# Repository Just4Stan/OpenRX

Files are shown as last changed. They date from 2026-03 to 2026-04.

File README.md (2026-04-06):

# OpenRX

Open-source ExpressLRS receiver family — four active boards:

- `OpenRX-Lite`: compact 2.4 GHz SX1281 receiver with ceramic antenna
- `OpenRX-Lite-UFL`: same as Lite with U.FL antenna connector
- `OpenRX-Mono`: single-LR1121 multi-band receiver with 1x U.FL
- `OpenRX-Gemini`: dual-LR1121 Gemini/Xrossband receiver with 2x U.FL

| Model | Band | RF | Front-End | Antenna | ELRS Target |
|---|---|-----|---|---|---|
| **Lite** | 2.4 GHz | SX1281 | 2450FM07D0034 BPF | Ceramic | `Unified_ESP32C3_2400_RX` |
| **Lite UFL** | 2.4 GHz | SX1281 | 2450FM07D0034 BPF | U.FL | `Unified_ESP32C3_2400_RX` |
| **Mono** | Multi-band | LR1121 | RFX2401C + SKY13414 + Johanson IPD | 1x U.FL | `Unified_ESP32C3_LR1121_RX` |
| **Gemini** | Xrossband | 2x LR1121 | 2x (RFX2401C + SKY13414 + Johanson IPD) | 2x U.FL | `Unified_ESP32C3_LR1121_RX` |

Mono and Gemini use the same firmware binary — `radio_nss_2` in hardware.json activates dual-radio mode.

## Active Schematics

- `OpenRX-Lite/esp32c3_sx1281_lite.kicad_sch`
- `OpenRX-Lite-UFL/esp32c3_sx1281_lite.kicad_sch`
- `OpenRX-Mono/esp32c3_lr1121_mono.kicad_sch`
- `OpenRX-Gemini/esp32c3_lr1121_gemini.kicad_sch`

## Documentation

- `OpenRX-Lite/DESIGN.md`
- `OpenRX-Lite-UFL/DESIGN.md`
- `OpenRX-Mono/DESIGN.md`
- `OpenRX-Gemini/DESIGN.md`

## Flashing

All boards expose `5V`, `GND`, `RX`, `TX` pads and a `BOOT` pad (GPIO9 to GND) for initial UART flashing. Mono and Gemini also have a tactile button on GPIO9. After first flash, use Wi-Fi OTA or Betaflight passthrough.

## ELRS Firmware Targets

Hardware JSON files are in `/shared/elrs-targets/`:

- `OpenRX Lite 2400.json`
- `OpenRX Mono LR1121.json`
- `OpenRX Gemini LR1121.json`
- `targets_entries.json`

## KiCad Libraries

All projects use KiCad 9 with project-local libraries only — no global library dependencies.

`shared/libs/` contains:

| Library | Contents |
|---|---|
| `OpenRX-Shared.kicad_sym` | Symbols: ESP32-C3, LR1121, SX1281, RFX2401C, SKY13414, TLV75533, Johanson IPD, 2450FM07D0034, antennas, LED, connectors |
| `OpenRX-Shared.pretty` | Footprints: QFN-14/16/24/32, X2SON, antenna, filter, LED, switch, solder pads |
| `OpenRX-Shared.3dshapes` | 3D models (.step + .wrl) |

All symbols include an `LCSC Part` property for JLCPCB BOM export.

## Datasheets

Shared local cache in `datasheets/common/`. All active IC/RF datasheets are present locally.

## Sourcing

Current low-stock / JLCPCB Global Sourcing candidates:

- `C255353` SKY13414-485LF
- `C19842466` 0900PC16J0042001E (consign from DigiKey)
- `C7498014` LR1121IMLTRT
- `C2151551` SX1281IMLTRT (for 1000 pcs Lite build)
- `C2651081` 2450FM07D0034

## License

**CERN Open Hardware Licence Version 2 - Strongly Reciprocal** ([CERN-OHL-S-2.0](https://ohwr.org/cern_ohl_s_v2.txt)). See [LICENSE](LICENSE).

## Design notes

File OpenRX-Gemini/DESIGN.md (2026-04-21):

# OpenRX-Gemini

Dual-LR1121 Gemini/Xrossband receiver. ESP32-C3 + 2x LR1121 + 2x RFX2401C + 2x SKY13414 + 2x Johanson IPD.

## Schematic

- Main sheet: `esp32c3_lr1121_gemini.kicad_sch`
- Radio A (U9 LR1121, U10 RFX2401C, U11 SKY13414): RF chain → `JP1` U.FL
- Radio B (U2 LR1121, U5 RFX2401C, U7 SKY13414): mirrors Radio A → `JP2` U.FL
- 2.4 GHz path per radio: `LR1121 RFIO_HF → 2450FM07D0034 (FL1/FL2) → RFX2401C → 0.3pF → SKY13414 RF4 → U.FL`
- Sub-GHz path per radio: `LR1121 → Johanson IPD (T1/T2) → SKY13414 RF1 (RX) / RF3 (TX HP) → U.FL`
- RF switch control (each radio controls its own switch): `DIO7 → V3, DIO8 → V2, V1 → GND`
- RFX2401C control (each radio controls its own FE): `DIO5 → RXEN, DIO6 → TXEN`
- ELRS sends `SetDioAsRfSwitch` to both radios simultaneously — wiring is symmetric so `radio_rfsw_ctrl` applies to both.

### SKY13414 Port Mapping (V1=GND, per switch)

| DIO7 (V3) | DIO8 (V2) | Port | Path |
|---|---|---|---|
| 0 | 0 | RF1 | Sub-GHz RX (IPD pin 6) |
| 1 | 0 | RF2 | NC |
| 0 | 1 | RF3 | Sub-GHz TX HP (IPD pin 9) |
| 1 | 1 | RF4 | 2.4GHz TX/RX (RFX2401C ANT) |

IPD TX_LP (pin 8) is disconnected — ELRS never uses LP PA on these boards.

### Status (2026-04-19, ELRS review)

All pre-fabrication schematic blockers resolved. Previously tracked bugs:

1. **DIO7-2 / DIO8-2 wiring:** FIXED — U7 (Radio B) V3/V2 tied to DIO7-2/DIO8-2, U11 (Radio A) V3/V2 tied to DIO7-1/DIO8-1. Each radio drives its own switch.
2. **Component swap:** DONE — filters migrated from `DEA102700LT-6307A2` to `2450FM07D0034T` (FL1 on Radio A, FL2 on Radio B), switches migrated from `SKY13588-460LF` to `SKY13414-485LF` (U7/U11).
3. **Ref designators:** filters renamed USB2→FL1 (Radio A) and USB1→FL2 (Radio B).

PCB routing, DRC, and on-hardware RF validation remain — see Release To-Do.

## Firmware

- ELRS target: `Unified_ESP32C3_LR1121_RX` (same binary as Mono)
- Hardware JSON: `/shared/elrs-targets/OpenRX Gemini LR1121.json`
- `radio_nss_2` enables dual-radio mode
- `radio_rfsw_ctrl: [15, 0, 0, 8, 8, 14, 0, 13]` — same as Mono, see Mono `DESIGN.md` for decode table (DIO5=RXEN, DIO6=TXEN, DIO7=V3, DIO8=V2)

## Flash Interface

- Pads: `5V`, `GND`, `RX`, `TX`
- `BOOT` pad + tactile button on GPIO9
- Hold BOOT/button during power-up for UART download mode
- Use Wi-Fi OTA after first flash

## Sourcing

- `C255353` SKY13414-485LF (x2)
- `C19842466` 0900PC16J0042001E (x2, consign from DigiKey)
- `C7498014` LR1121IMLTRT (x2)
- `C2651081` 2450FM07D0034T (x2)
- `C19213` RFX2401C (x2)

## Release To-Do

- Finish PCB routing / DRC
- Validate symmetric RF performance across both chains (NanoVNA)
- Run Gemini / Xrossband link validation on two LR1121-equipped TXs
- CE / RED pre-scan for dual-band operation

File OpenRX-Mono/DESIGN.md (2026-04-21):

# OpenRX-Mono

Single-LR1121 multi-band receiver. ESP32-C3 + LR1121 + RFX2401C + SKY13414 + Johanson IPD.

## Schematic

- Main sheet: `esp32c3_lr1121_mono.kicad_sch`
- Sub-GHz RX: `LR1121 pins 29-30 → IPD (T1) RX → SKY13414 RF1 → ANT → JP1 U.FL`
- Sub-GHz TX HP: `LR1121 pin 32 → IPD (T1) TX_HP → SKY13414 RF3 → ANT → JP1 U.FL`
- Sub-GHz TX LP: disconnected (IPD TX_LP pin 8 = NC, ELRS never uses LP PA)
- 2.4 GHz path: `LR1121 RFIO_HF → 2450FM07D0034 (USB2) → RFX2401C TXRX → PA/LNA → RFX2401C ANT → C16 0.3pF → SKY13414 RF4 → ANT → JP1 U.FL`
- RF switch control: `DIO7 → V3, DIO8 → V2, V1 → GND`
- RFX2401C control: `DIO5 → RXEN, DIO6 → TXEN`

### SKY13414 Port Mapping (V1=GND)

| DIO7 (V3) | DIO8 (V2) | Port | Path |
|---|---|---|---|
| 0 | 0 | RF1 | Sub-GHz RX (IPD pin 6) |
| 1 | 0 | RF2 | NC |
| 0 | 1 | RF3 | Sub-GHz TX HP (IPD pin 9) |
| 1 | 1 | RF4 | 2.4GHz TX/RX (RFX2401C ANT) |

IPD TX_LP (pin 8) is disconnected — ELRS never uses LP PA on these boards.

### 2450FM07D0034 Impedance Note

Filter pin 1 (chipset side) is 40 ohm, designed for SX1280/SX1281. LR1121 RFIO_HF is 50 ohm. Mismatch gives ~19 dB return loss (VSWR 1.25), only 0.05 dB mismatch loss — negligible. The filter's own internal return loss (14 dB typ) dominates. Keep as-is.

## Firmware

- ELRS target: `Unified_ESP32C3_LR1121_RX`
- Hardware JSON: `/shared/elrs-targets/OpenRX Mono LR1121.json`
- `radio_rfsw_ctrl: [15, 0, 0, 8, 8, 14, 0, 13]` — DIO5=RXEN, DIO6=TXEN, DIO7=V3, DIO8=V2

### rfsw_ctrl Decode

| Index | Mode | Value | Binary | DIO5 | DIO6 | DIO7 | DIO8 |
|---|---|---|---|---|---|---|---|
| 0 | Enable | 15 | 1111 | on | on | on | on |
| 1 | Standby | 0 | 0000 | 0 | 0 | 0 | 0 |
| 2 | SubGHz RX | 0 | 0000 | 0 | 0 | 0 | 0 |
| 3 | SubGHz TX LP | 8 | 1000 | 0 | 0 | 0 | 1 |
| 4 | SubGHz TX HP | 8 | 1000 | 0 | 0 | 0 | 1 |
| 5 | 2.4GHz TX | 14 | 1110 | 0 | 1 | 1 | 1 |
| 6 | unused | 0 | - | - | - | - | - |
| 7 | 2.4GHz RX | 13 | 1101 | 1 | 0 | 1 | 1 |

### GPIO Map

| GPIO | Function | LR1121 Pin |
|---|---|---|
| 1 | IRQ (DIO1) | 24 |
| 2 | RST | 6 |
| 3 | BUSY (DIO0) | 25 |
| 4 | MOSI | via SPI |
| 5 | MISO | via SPI |
| 6 | SCK | via SPI |
| 7 | NSS | via SPI |
| 8 | LED | - |
| 9 | Button | - |

## Flash Interface

- Pads: `5V`, `GND`, `RX`, `TX`
- `BOOT` pad + tactile button on GPIO9
- Hold BOOT/button during power-up for UART download mode
- Use Wi-Fi OTA after first flash

## Sourcing

- `C255353` SKY13414-485LF — 28K LCSC stock
- `C19842466` 0900PC16J0042001E — consign from DigiKey (~$0.49), 0 LCSC stock
- `C7498014` LR1121IMLTRT
- `C2651081` 2450FM07D0034
- `C19213` RFX2401C

## Release To-Do

- Finish PCB routing / DRC
- Validate RF path switching and rfsw_ctrl on hardware (NanoVNA)
- Run CE / RED pre-scan for 2.4 GHz and sub-GHz operation

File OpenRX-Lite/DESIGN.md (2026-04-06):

# OpenRX-Lite (Ceramic Antenna)

ESP32-C3 + SX1281, 2.4GHz only, ceramic antenna. Smallest and cheapest OpenRX receiver.

## Board Preview

| Front | Back |
|---|---|
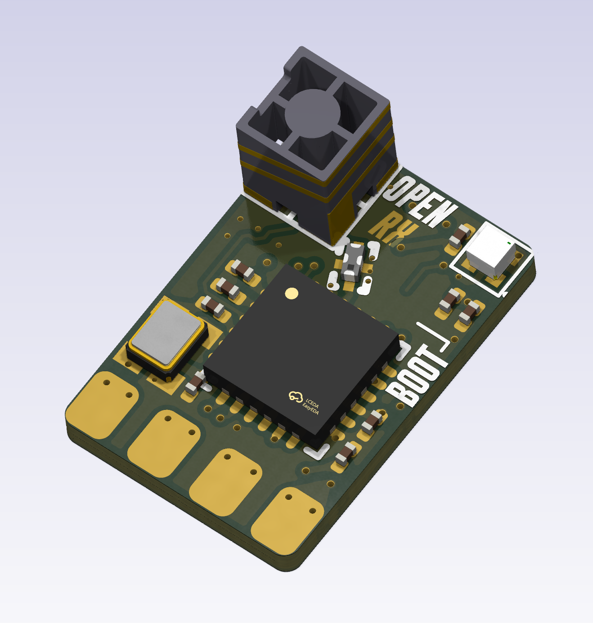
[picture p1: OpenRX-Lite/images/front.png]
Front
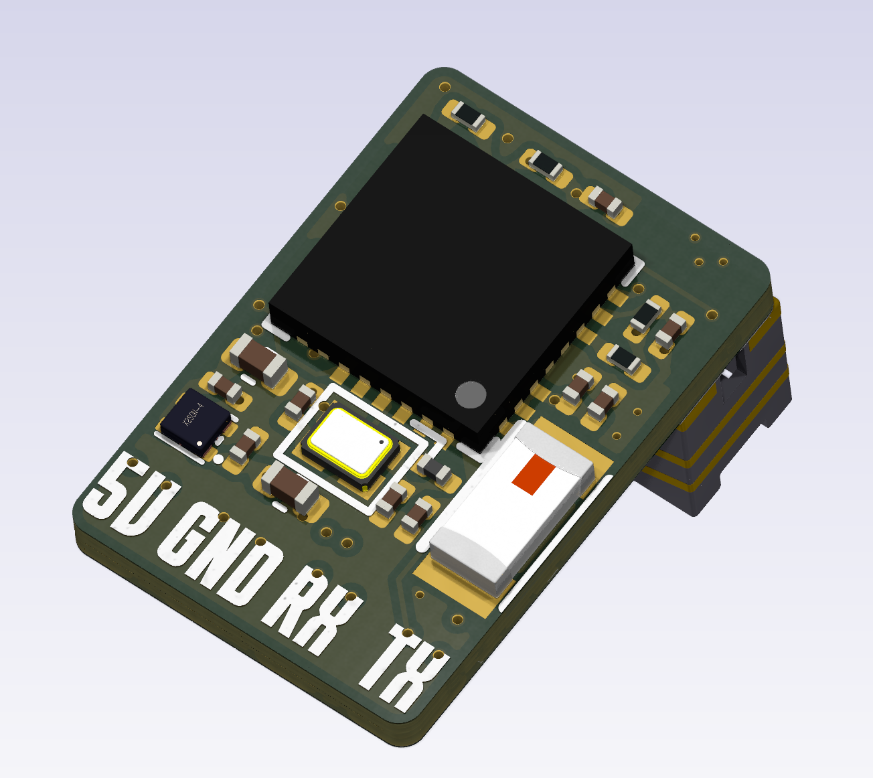
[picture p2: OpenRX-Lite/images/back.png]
Back
|  |  |

## Schematic

- Main sheet: `esp32c3_sx1281_lite.kicad_sch`
- RF chain: `SX1281 RFIO (pin 22) → 2450FM07D0034 (FL1) → 2450AT18A100E (AE1)`
- No RF front-end (PA/LNA), no RF switch, no sub-GHz
- 2450FM07D0034 pin 1 (40 ohm) matched to SX1281 RFIO — no mismatch
- TX power limited to SX1281 native +12.5 dBm (no PA)

### GPIO Map

| GPIO | Function |
|---|---|
| 2 | RST |
| 3 | BUSY |
| 4 | SCK |
| 5 | DIO1 |
| 6 | MISO |
| 7 | MOSI |
| 8 | NSS |
| 10 | LED |

Note: SPI pin mapping differs from Mono/Gemini. Lite uses GPIO4=SCK, GPIO6=MISO, GPIO7=MOSI, GPIO8=NSS. Mono uses GPIO6=SCK, GPIO5=MISO, GPIO4=MOSI, GPIO7=NSS. Different hardware.json required.

### No Boot Button

GPIO9 has a 10K pull-up but no physical switch. Enter UART download mode by shorting the BOOT pad to GND during power-up. WiFi mode cannot be entered at runtime without UART — firmware must be pre-configured or OTA-enabled on first flash.

## Firmware

- ELRS target: `Unified_ESP32C3_2400_RX`
- Hardware JSON: `/shared/elrs-targets/OpenRX Lite 2400.json`
- `power_values: [13]` — single power level, +12.5 dBm SX1281 native output

## Flash Interface

- Pads: `5V`, `GND`, `RX`, `TX`
- `BOOT` pad: short to GND during power-up to enter UART download mode
- Use Wi-Fi OTA after first flash

## Sourcing

- All parts LCSC basic/preferred where possible
- `C2651081` 2450FM07D0034 — 2.4GHz bandpass filter
- `C2151551` SX1281IMLTRT — watch stock for volume runs
- `C89334` 2450AT18A100E — ceramic chip antenna

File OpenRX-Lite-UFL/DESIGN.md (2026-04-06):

# OpenRX-Lite UFL

ESP32-C3 + SX1281, 2.4GHz only, UFL antenna connector. Same circuit as Lite ceramic, different antenna interface.

## Board Preview

| Front | Back |
|---|---|
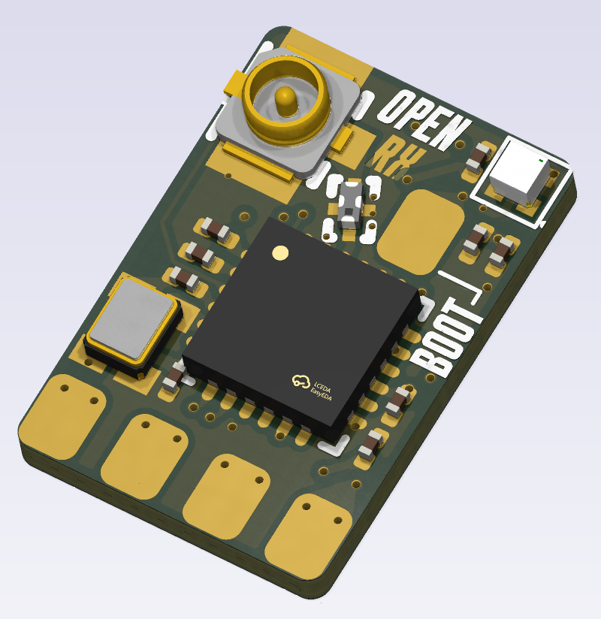
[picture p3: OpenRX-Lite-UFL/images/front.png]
Front
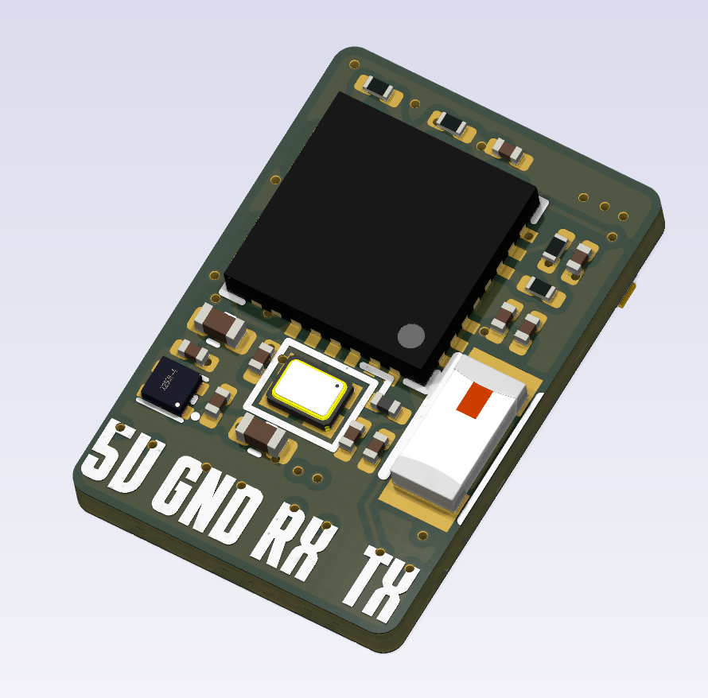
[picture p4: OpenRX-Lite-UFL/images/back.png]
Back
|  |  |

## Schematic

- Main sheet: `esp32c3_sx1281_lite.kicad_sch`
- RF chain: `SX1281 RFIO (pin 22) → 2450FM07D0034 (FL1) → U.FL-R-SMT-1(80) (JP1)`
- AE1 (2450AT18A100E) still in BOM — DNP or WiFi antenna for ESP32-C3
- No RF front-end (PA/LNA), no RF switch, no sub-GHz
- 2450FM07D0034 output is 50 ohm → U.FL is 50 ohm. Clean match.

### GPIO Map

Same as Lite ceramic — see `OpenRX-Lite/DESIGN.md`.

### No Boot Button

Same as Lite ceramic — GPIO9 pull-up only, no physical switch.

## Firmware

- ELRS target: `Unified_ESP32C3_2400_RX` (same as ceramic Lite)
- Hardware JSON: `/shared/elrs-targets/OpenRX Lite 2400.json`

## Flash Interface

- Pads: `5V`, `GND`, `RX`, `TX`
- `BOOT` pad: short to GND during power-up to enter UART download mode
- Use Wi-Fi OTA after first flash

## Sourcing

- All parts LCSC basic/preferred where possible
- `C2651081` 2450FM07D0034 — 2.4GHz bandpass filter
- `C2151551` SX1281IMLTRT — watch stock for volume runs
- `C88374` U.FL-R-SMT-1(80) — antenna connector

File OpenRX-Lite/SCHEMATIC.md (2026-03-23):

# OpenRX-Lite Schematic Documentation

Budget 2.4GHz ExpressLRS receiver. No PA/LNA, no UFL -- direct SX1281 to ceramic chip antenna.

- PCB: 16x12mm, 2-layer, 1.0mm thickness
- Target BOM: EUR 3-4
- Input: 3.3-5V from flight controller

## Block Diagram

```
                                    +3.3V
                                      |
  +-----+    +--------+    +---------+----------+
  | FC   |    |ME6211  |    |                    |
  | 5V---|----| LDO    |----|  ESP32-C3FH4       |
  | GND--|--+-| 3.3V   |    |  (QFN-32, 5x5mm)  |
  | TX---|--|-|--------|----| GPIO1/RX           |
  | RX---|--|-|--------|----| GPIO0/TX           |
  +-----+  | |        |    |                    |    SPI Bus
            | +--------+    |  GPIO4/SCK  -------+--------+
            |               |  GPIO7/MOSI -------+-----+  |
            |               |  GPIO6/MISO -------+--+  |  |
            |               |  GPIO8/NSS  -------+-+|  |  |
            |               |  GPIO5/DIO1 ------+| ||  |  |
            |               |  GPIO3/BUSY -----+|| ||  |  |
            |               |  GPIO2/NRST ----+||| ||  |  |
            |               |                 |||| ||  |  |
            |     40MHz     |  XTAL_P/N       |||| ||  |  |
            |    +-----+    |    |  |          |||| ||  |  |
            |    | XTAL|----+----+--+          |||| ||  |  |
            |    +-----+    |                  |||| ||  |  |
            |               | GPIO10 ---> WS2812B (opt)    |
            |               | GPIO9  ---> BOOT btn         |
            |               | GPIO18 ---> USB D- (TP)      |
            |               | GPIO19 ---> USB D+ (TP)      |
            |               +----------+   |||| ||  |  |
            |                              |||| ||  |  |
            |               +----------+   |||| ||  |  |
            |    52MHz      |SX1281    |   |||| ||  |  |
            |   +------+    |IMLTRT   |   |||| ||  |  |
            |   | TCXO |----|XTA      |   |||| ||  |  |
            |   +------+    |         |   |||| ||  |  |
            |               |NRESET---+---+||| ||  |  |
            |               |BUSY  --------+|| ||  |  |
            |               |DIO1  ---------+| ||  |  |
            |               |NSS   ----------+ ||  |  |
            |               |MISO  -------------+  |  |
            |               |MOSI  ----------------+  |
            |               |SCK   -------------------+
            |               |         |
            |               |  RFIO   |
            |               +----+----+
            |                    |
            |               L-match network
            |               2.2nH + 1.0pF
            |                    |
            |               +----------+
            |               | Ceramic  |
            |               | Antenna  |
            |               | 2450AT   |
            |               +----------+
            |
            +--- GND plane
```

## Power Supply (U3: ME6211C33M5G-N)

SOT-23-5, 500mA, LDO 3.3V regulator. LCSC C82942.

```
         5V IN
          |
          +--+--[C1 10uF]--+--GND
          |  |              |
          |  +--[C2 100nF]--+
          |
     +----+----+
     |1  VIN   |
     |         |
     |2  VOUT--+--+--[C3 22uF]--+--GND
     |         |  |              |
     |3  CE    |  +--[C4 100nF]--+
     |   (=VIN)|  |
     |4  GND   |  +--- 3.3V RAIL
     |5  NC    |
     +---------+
```

### Pin-by-pin: ME6211C33M5G-N (SOT-23-5)

| Pin | Name | Connection |
|-----|---|---|
| 1 | VIN | 5V input rail. C1 (10uF 0603 X5R) + C2 (100nF 0402 X7R) to GND |
| 2 | VOUT | 3.3V output rail. C3 (22uF 0603 X5R) + C4 (100nF 0402 X7R) to GND |
| 3 | CE (chip enable) | Tied to VIN (always on) |
| 4 | GND | Ground |
| 5 | NC | No connect |

## ESP32-C3FH4 (U1, QFN-32, 5x5mm)

LCSC C2858491. RISC-V single core, 160MHz, 4MB internal flash, WiFi+BLE.

### Pin-by-pin: ESP32-C3FH4 (QFN-32)

| Pin | Name | Connection | Notes |
|-----|---|---|---|
| 1 | GND | GND | |
| 2 | GND | GND | |
| 3 | 3V3 | 3.3V rail, 100nF (C5) to GND | Main power |
| 4 | EN (CHIP_EN) | 10k (R1) pull-up to 3.3V + 1uF (C6) to GND | RC delay per Espressif spec. Provides stable power-on reset. |
| 5 | GPIO4 | SX1281 SCK (pin 18) | SPI clock |
| 6 | GPIO5 | SX1281 DIO1 (pin 5) | Radio interrupt (active high) |
| 7 | GPIO6 | SX1281 MISO (pin 16) | SPI data from radio |
| 8 | GPIO7 | SX1281 MOSI (pin 17) | SPI data to radio |
| 9 | GPIO8 | SX1281 NSS (pin 19) + 10k (R2) pull-up to 3.3V | SPI chip select (active low). Pull-up keeps radio deselected during ESP boot. |
| 10 | GPIO9 | BOOT button (SW1) to GND + 10k (R3) pull-up to 3.3V | Hold low during reset to enter USB/UART bootloader. Internal pull-up exists but external recommended. |
| 11 | GPIO10 | WS2812B LED data (D1) | Optional status LED. Series 100R (R4) recommended. |
| 12 | GND | GND | |
| 13 | GPIO18 (USB_D-) | Test pad TP1 | Native USB for flashing. Optional -- can use UART instead. |
| 14 | GPIO19 (USB_D+) | Test pad TP2 | Native USB for flashing. Optional. |
| 15 | GPIO3 | SX1281 BUSY (pin 4) | Radio busy status (active high). Poll before SPI commands. |
| 16 | GPIO2 | SX1281 NRESETn (pin 3) | Radio hardware reset (active low). ESP drives low to reset SX1281. |
| 17 | GPIO1 (RX) | FC connector pad TX (CRSF from FC) | UART RX. FC TX connects to ESP RX. 3.3V logic. |
| 18 | GPIO0 (TX) | FC connector pad RX (CRSF to FC) | UART TX. ESP TX connects to FC RX. |
| 19 | GND | GND | |
| 20 | XTAL_P | 40MHz crystal (Y1) pin 1 + 10pF (C7) to GND | Crystal load cap. Place crystal close to pins 20/21. |
| 21 | XTAL_N | 40MHz crystal (Y1) pin 3 + 10pF (C8) to GND | Crystal load cap. |
| 22-30 | GND/NC | GND or NC per datasheet | Unused GPIO and supply pins tied to GND |
| 31 | GND | GND | |
| 32 | GND | GND | |
| EP | Exposed pad | GND | Thermal pad, multiple vias to ground plane |

**Critical notes for ESP32-C3FH4:**
- Pin 4 (EN) RC time constant: 10k * 1uF = 10ms. This ensures clean power-on reset.
- GPIO9 is the boot mode strapping pin. HIGH = normal boot from flash. LOW during reset = download mode.
- GPIO8 is also a strapping pin. Must be HIGH during boot (pull-up on NSS line handles this).
- GPIO2 is a strapping pin. Defaults to HIGH (floating). OK since SX1281 NRESET is active low.
- The ESP32-C3FH4 has 4MB flash internal -- no external flash needed.
- 40MHz crystal is mandatory. Cannot use internal RC oscillator for WiFi/BLE.
- Thermal pad MUST be soldered to GND with thermal vias.

## SX1281IMLTRT (U2, QFN-24, 4x4mm)

LCSC C2151551. 2.4GHz LoRa/FLRC/FSK transceiver. Used in LDO mode (no external inductor).

### Pin-by-pin: SX1281IMLTRT (QFN-24)

| Pin | Name | Connection | Notes |
|-----|---|---|---|
| 1 | VDD | 3.3V through 100nF (C9) to GND | Digital supply |
| 2 | VDD_IN | 3.3V through 100nF (C10) to GND | CRITICAL: Must be connected. Main power input for internal LDO/DC-DC. |
| 3 | NRESETn | ESP32-C3 GPIO2 (pin 16) + 10k (R5) pull-up to 3.3V + 100nF (C11) to GND | Active low reset. RC provides power-on reset. ESP can drive low for hard reset. |
| 4 | BUSY | ESP32-C3 GPIO3 (pin 15) | Active high when radio is processing a command. Poll before SPI transactions. |
| 5 | DIO1 | ESP32-C3 GPIO5 (pin 6) | Main interrupt output. Directly connected. |
| 6 | DIO2 | NC | Not used in this design. Can be used for RF switch control in designs with PA/LNA. |
| 7 | DIO3 | NC | Not used. Can output 32MHz clock for TCXO enable but we use always-on TCXO. |
| 8 | GND | GND | |
| 9 | GND | GND | |
| 10 | VR_PA | 470nF (C12) to GND | LDO mode: This is the PA regulator output. 470nF decoupling required. NO inductor (inductor only needed in DC-DC mode). |
| 11 | VDD | 3.3V through 100nF (C13) to GND | RF/analog supply |
| 12 | XTA | 52MHz TCXO output (Y2 pin 3) | TCXO clock input. AC coupling cap may be needed (10pF, C14) depending on TCXO output type. If TCXO is clipped sine output, direct connection OK. |
| 13 | XTB | NC (floating) | Only used in crystal mode. Leave floating for TCXO mode. |
| 14 | GND | GND | |
| 15 | RFIO | L-match network to antenna | See RF Path section below |
| 16 | MISO | ESP32-C3 GPIO6 (pin 7) | SPI data output |
| 17 | MOSI | ESP32-C3 GPIO7 (pin 8) | SPI data input |
| 18 | SCK | ESP32-C3 GPIO4 (pin 5) | SPI clock input |
| 19 | NSS | ESP32-C3 GPIO8 (pin 9) + 10k (R2) pull-up to 3.3V | SPI chip select, active low. Shared pull-up with ESP side. |
| 20 | GND | GND | |
| 21 | GND | GND | |
| 22 | GND | GND | |
| 23 | GND | GND | |
| 24 | GND | GND | |
| EP | Exposed pad | GND | Thermal pad. Multiple vias to GND plane. |

**Critical notes for SX1281:**
- LDO mode selected: VR_PA (pin 10) gets 470nF cap only. No inductor.
- DC-DC mode would require 15nH inductor on VR_PA but adds layout complexity on 2-layer board. Not worth it for a receiver.
- VDD_IN (pin 2) MUST be connected to 3.3V. Common mistake to leave it floating.
- TCXO mode: Set register UseRegulatorMode and configure TCXO in firmware. DIO3 can control TCXO power but we run TCXO always-on from 3.3V for simplicity.
- Max SPI clock: 16MHz. ESP32-C3 SPI peripheral should be configured accordingly.
- BUSY must be polled before every SPI transaction. Do not rely on timing.

## 52MHz TCXO (Y2: OW7EL89CENUNFAYLC-52M)

LCSC C22434896. SMD 2016-4P (2.0x1.6mm). YXC, 3.3V, +/-0.5ppm.

### Pin-by-pin: TCXO (SMD2016-4P)

| Pin | Name | Connection |
|-----|---|---|
| 1 | VDD | 3.3V through 100nF (C15) to GND |
| 2 | GND | GND |
| 3 | OUTPUT | SX1281 XTA (pin 12). Direct connection if clipped sine output. Add 10pF AC coupling cap (C14) if DC blocking needed. |
| 4 | GND | GND |

**Notes:**
- TCXO provides temperature-stable 52MHz reference. Prevents frequency drift disconnections that plague crystal-based ELRS receivers.
- +/-0.5ppm stability is excellent. SX1281 datasheet requires better than +/-5ppm for reliable FLRC mode.
- Always-on (powered from 3.3V rail directly). No DIO3 control needed.
- Place close to SX1281 XTA pin. Keep trace short and away from digital signals.

## 40MHz Crystal (Y1: CJ17-400001010B20)

LCSC C2875272. SMD 1612-4P (1.6x1.2mm). Changjing, 10pF load, +/-10ppm.

### Pin-by-pin: Crystal (SMD1612-4P)

| Pin | Name | Connection |
|-----|---|---|
| 1 | XIN | ESP32-C3 XTAL_P (pin 20) + 10pF (C7) to GND |
| 2 | GND | GND |
| 3 | XOUT | ESP32-C3 XTAL_N (pin 21) + 10pF (C8) to GND |
| 4 | GND | GND |

**Notes:**
- 10pF load caps match crystal specification. Actual capacitance seen by crystal = (C_load1 * C_load2) / (C_load1 + C_load2) + C_stray. With 10pF caps and ~2-3pF stray, effective load is ~7-8pF. May need to adjust to 12pF caps if frequency is off.
- Place as close to ESP32-C3 XTAL pins as possible. Route traces as short differential pair.
- Guard ring on GND plane around crystal traces recommended.
- Keep copper pour away from crystal on the other layer.

## RF Path (Antenna Matching)

No PA/LNA. Direct connection from SX1281 RFIO to ceramic antenna through L-match network.

```
SX1281          L-match              Ceramic Antenna
RFIO  ---[L1 2.2nH]---+---[feed]--- 2450AT18A100E
(pin 15)               |             (Johanson)
                   [C16 1.0pF]
                       |
                      GND
```

### Components:
- L1: 2.2nH inductor, 0402, high-Q (>30 at 2.4GHz). LCSC basic part preferred.
- C16: 1.0pF capacitor, 0402, C0G/NP0. Tight tolerance (+/-0.1pF if possible).

### Ceramic Antenna: 2450AT18A100E (ANT1)

LCSC C89334. Johanson, 3.2x1.6mm chip antenna.

**Notes:**
- Antenna MUST be placed at PCB edge with ground plane keepout per Johanson application note.
- Minimum 1mm clearance from antenna feed to GND pour on top layer.
- Ground plane on bottom layer should extend under antenna for return path.
- Antenna impedance is nominally 50 ohm but varies with ground plane geometry. L-match values (2.2nH/1.0pF) are starting points -- tune with VNA on actual PCB.
- No copper (signal or ground) on the same layer as antenna within keepout zone.
- Performance will be significantly worse than external antenna. Expected range: 200-500m line of sight with ELRS 500Hz mode. Adequate for typical FPV use (proximity/indoor/whoops).

## WS2812B LED (D1, Optional)

Standard addressable RGB LED for status indication.

| Connection | Detail |
|---|---|
| VDD | 3.3V (WS2812B works at 3.3V, some variants need 5V -- check datasheet) |
| DIN | ESP32-C3 GPIO10 (pin 11) through 100R series resistor (R4) |
| DOUT | NC |
| GND | GND |
| Decoupling | 100nF (C17) close to VDD pin |

Note: WS2812B is optional. Omit to save BOM cost and board space. ELRS firmware can function without LED.

## Boot Button (SW1)

Tactile switch, normally open.

| Connection | Detail |
|---|---|
| One side | ESP32-C3 GPIO9 (pin 10) |
| Other side | GND |
| Pull-up | 10k (R3) from GPIO9 to 3.3V |

Hold button during power-on or reset to enter bootloader (USB or UART download mode).

Note: For production, this can be replaced with solder pads or omitted entirely if UART flashing via FC connection is sufficient. ELRS uses its own bootloader passthrough via UART.

## Connector Pads (J1)

4 castellated or solder pads, 1.27mm pitch, at PCB edge.

| Pad | Signal | Notes |
|-----|---|---|
| 1 | 5V | Power input from FC. 3.3-5V range (LDO input). |
| 2 | GND | Ground |
| 3 | TX | ESP32-C3 GPIO0/TX. CRSF data TO flight controller. Connect to FC RX pad. |
| 4 | RX | ESP32-C3 GPIO1/RX. CRSF data FROM flight controller. Connect to FC TX pad. |

## Test Pads

| Pad | Signal | Notes |
|-----|---|---|
| TP1 | USB D- | ESP32-C3 GPIO18. For USB flashing during development. |
| TP2 | USB D+ | ESP32-C3 GPIO19. For USB flashing during development. |

## Complete Decoupling Capacitor Summary

| Designator | Value | Package | Location | IC/Pin |
|---|---|---|---|---|
| C1 | 10uF | 0603 X5R 10V | LDO input | U3 VIN |
| C2 | 100nF | 0402 X7R 16V | LDO input | U3 VIN |
| C3 | 22uF | 0603 X5R 10V | LDO output | U3 VOUT |
| C4 | 100nF | 0402 X7R 16V | LDO output | U3 VOUT |
| C5 | 100nF | 0402 X7R 16V | ESP32 3V3 | U1 pin 3 |
| C6 | 1uF | 0402 X5R 10V | ESP32 EN | U1 pin 4 (with R1) |
| C7 | 10pF | 0402 C0G 50V | Crystal load | U1 XTAL_P (pin 20) |
| C8 | 10pF | 0402 C0G 50V | Crystal load | U1 XTAL_N (pin 21) |
| C9 | 100nF | 0402 X7R 16V | SX1281 VDD | U2 pin 1 |
| C10 | 100nF | 0402 X7R 16V | SX1281 VDD_IN | U2 pin 2 |
| C11 | 100nF | 0402 X7R 16V | SX1281 NRESET | U2 pin 3 (with R5) |
| C12 | 470nF | 0402 X5R 10V | SX1281 VR_PA | U2 pin 10 (LDO mode) |
| C13 | 100nF | 0402 X7R 16V | SX1281 VDD | U2 pin 11 |
| C14 | 10pF | 0402 C0G 50V | TCXO AC coupling | Y2 out to U2 XTA (optional) |
| C15 | 100nF | 0402 X7R 16V | TCXO VDD | Y2 pin 1 |
| C16 | 1.0pF | 0402 C0G 50V | Antenna match | Shunt to GND in L-match |
| C17 | 100nF | 0402 X7R 16V | WS2812B VDD | D1 (optional) |

## Complete Resistor Summary

| Designator | Value | Package | Location |
|---|---|---|---|
| R1 | 10k | 0402 | ESP32 EN pull-up |
| R2 | 10k | 0402 | SPI NSS pull-up (shared ESP/SX1281) |
| R3 | 10k | 0402 | BOOT button pull-up |
| R4 | 100R | 0402 | WS2812B data series resistor (optional) |
| R5 | 10k | 0402 | SX1281 NRESET pull-up |

## Complete Inductor Summary

| Designator | Value | Package | Location |
|---|---|---|---|
| L1 | 2.2nH | 0402 | Antenna L-match series inductor |

## Design Notes and Considerations

### Power Budget
- ESP32-C3 active (WiFi off, CPU running): ~30mA
- SX1281 RX mode: ~7mA
- SX1281 TX mode (no PA): ~25mA at +12.5dBm
- TCXO: ~1.5mA
- WS2812B: ~1mA idle, ~20mA full white
- Total typical (RX mode): ~40mA
- ME6211 500mA capacity provides ample margin

### Layout Priorities (2-layer board)
1. SX1281 ground pad: Maximize thermal vias to bottom GND plane
2. ESP32-C3 ground pad: Same treatment
3. Crystal placement: As close to ESP XTAL pins as physically possible
4. TCXO placement: As close to SX1281 XTA as possible
5. Antenna: At PCB edge, ground plane keepout per Johanson app note
6. Decoupling caps: Each cap within 1mm of its associated IC pin
7. SPI traces: Keep short, matched length not critical at 16MHz max
8. RF trace (RFIO to antenna): 50 ohm controlled impedance if possible. On 2-layer 1.0mm FR4, approximately 1.8mm trace width for 50 ohm microstrip. Short trace length minimizes mismatch impact.

### 2-Layer Stackup (JLCPCB 1.0mm)
- Top: Components, signal routing, RF trace
- Bottom: Continuous GND plane (maximise pour). Route signals on top only where possible.

### Firmware Considerations
- ExpressLRS firmware must be configured for:
  - SX1281 (not SX1280 -- SX1281 has LNA built in)
  - TCXO mode (not crystal)
  - LDO mode (not DC-DC)
  - No PA/LNA control pins
  - GPIO mappings matching this schematic
- CRSF protocol on UART at 420000 baud (ELRS default)
- Binding phrase set in firmware build

### Known Limitations
- No diversity (single antenna, single radio)
- No PA: TX power limited to SX1281 native +12.5dBm max
- No LNA: RX sensitivity limited to SX1281 native (~-105dBm for LoRa, ~-98dBm for FLRC)
- Range estimate: 200-500m LOS at 500Hz, 1-2km at 50Hz. Adequate for proximity/indoor/whoop flying.
- 2-layer RF: Impedance control less precise than 4-layer. Antenna match will need bench tuning.
- Ceramic antenna: ~2-3dB gain penalty vs external dipole/T-antenna

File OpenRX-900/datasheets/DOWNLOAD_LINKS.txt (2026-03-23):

# OpenRX-900 Datasheets - Download Manually

## LR1121 (already downloaded as LR1121_datasheet_v1.1.pdf)
https://cdn.hackaday.io/files/1901428135035328/LR1121_data_sheet_V1_1.pdf

## ESP32-C3 Datasheet
https://www.espressif.com/sites/default/files/documentation/esp32-c3_datasheet_en.pdf

## ESP32-C3 Hardware Design Guidelines
https://www.espressif.com/sites/default/files/documentation/esp32-c3_hardware_design_guidelines_en.pdf

## ME6211C LDO Datasheet
https://datasheet.lcsc.com/lcsc/1811131510_MICRONE-Nanjing-Micro-One-Elec-ME6211C33M5G-N_C82942.pdf

## LR1121 User Manual
https://www.mouser.com/pdfDocs/UserManual_LR1121_v1_1.pdf

## LR1121 PCB Design Guidelines (AN1200.66)
https://www.semtech.com (search for AN1200.66)

## LR1121 IPD Reference Design (AN1200.76)
https://www.semtech.com (search for AN1200.76)

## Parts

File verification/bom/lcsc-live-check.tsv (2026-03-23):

LCSC | MPN | PriceUSD | Availability | Inventory | Description
C106225 | RC0201FR-0710KL | 0.0006 | InStock | 1342400 | 50mW 10kΩ 25V Thick Film Resistor ±1% ±200ppm/℃ 0201 Chip Resistor - Surface Mount RoHS
C152351 | 479480001 | 0.7028 | InStock | 18195 | RF ANTENNA 2.4G Surface Mount,3.2x4mm
C15525 | CL05A106MQ5NUNC | 0.0037 | InStock | 2592700 | 10uF ±20% 6.3V Ceramic Capacitor X5R 0402
C19213 | RFX2401C | 0.5059 | InStock | 59827 | 2V~3.6V ZigBee 2.4GHz~2.5GHz QFN-16-EP(3x3) RF Front End (LNA + PA) RoHS
C19842466 | 0900PC16J0042001E | 0.5236 | OutOfStock | 0 | 10dB 868MHz~928MHz 1dB 50Ω:50Ω Balun RoHS
C20069240 | CGA0201C0G100J500ET | 0.0003 | InStock | 69600 | 10pF ±5% 50V Ceramic Capacitor C0G 0201
C206441 | LQP03TN24NH02D | 0.0050 | InStock | 8600 | 140mA 24nH 2.3Ω Thick Film Inductor ±3% 0201 Fixed Inductors RoHS
C2151551 | SX1281IMLTRT | 2.2643 | InStock | 1168 | 2Mbps -132dBm 2.4GHz~2.5GHz 2.4GHz 1.8V~3.7V QFN-24-EP(4x4) RF Transceiver ICs RoHS
C22434888 | OW2EL89CENUXFMYLC-32M | 0.4605 | InStock | 2782 | 32MHz SMD3225-4P Oscillators RoHS
C22434896 | OW7EL89CENUNFAYLC-52M | 0.4208 | InStock | 12605 | 52MHz SMD2016-4P Oscillators RoHS
C23733 | CL05A475MP5NRNC | 0.0028 | InStock | 2177450 | 4.7uF ±20% 10V Ceramic Capacitor X5R 0402
C270364 | 0201WMF1003TEE | 0.0005 | InStock | 2096600 | 100kΩ ±1% 50mW 0201 Thick Film Resistor
C274342 | RC0201FR-07220RL | 0.0005 | InStock | 22100 | 50mW 220Ω 25V Thick Film Resistor ±1% ±200ppm/℃ 0201 Chip Resistor - Surface Mount RoHS
C2858491 | ESP32-C3FH4 | 1.5592 | InStock | 1783 | QFN-32-EP(5x5) RF Transceiver Modules and Modems RoHS
C2861882 | TLV75533PDQNR | 0.0915 | InStock | 2610 | Linear Voltage Regulator IC Positive Fixed 1 Output 500mA X2-SON-4-EP(1x1)
C2875272 | CJ17-400001010B20 | 0.1484 | InStock | 15 | Crystal 40MHz ±10ppm 10pF SMD1612-4P
C5349953 | XL-1010RGBC-2812B | 0.0395 | InStock | 1045460 | SMD,1x1mm LED Addressable, Specialty RoHS
C574024 | DEA102700LT-6307A2 | 0.0544 | InStock | 5385 | 50Ω 0.45dB SMD-4P,1x0.5mm RF Filters RoHS
C62164 | 0201CG180J500NT | 0.0004 | InStock | 280900 | 18pF ±5% 50V Ceramic Capacitor C0G 0201
C62548 | 0201B221K500NT | 0.0004 | InStock | 209600 | 220pF ±10% 50V Ceramic Capacitor X7R 0201
C66942 | 0201B102K500NT | 0.0004 | InStock | 537800 | 1nF ±10% 50V Ceramic Capacitor X7R 0201
C6808014 | AHW1608FE100KTF | 0.0174 | InStock | 39500 | 280mA 10uH 2.4Ω Wire-wound chip inductor ±10% 0603 Fixed Inductors RoHS
C7498014 | LR1121IMLTRT | 3.0399 | InStock | 1439 | 101.5Kbps -108dBm 1.8V~3.7V QFN-32-EP(5x5) RF Transceiver ICs RoHS
C76935 | GRM033R61A105ME44D | 0.0016 | InStock | 676000 | 1uF ±20% 10V Ceramic Capacitor X5R 0201
C76939 | GRM033R61E104KE14D | 0.0018 | InStock | 1336800 | 100nF ±10% 25V Ceramic Capacitor X5R 0201
C85926 | GRM033R60J474KE90D | 0.0014 | InStock | 508900 | 470nF ±10% 6.3V Ceramic Capacitor X5R 0201
C88374 | U.FL-R-SMT-1(80) | 0.0769 | InStock | 243610 | Connector Receptacle IPEX Male Pin 50Ω Surface Mount
C89334 | 2450AT18A100E | 0.3117 | InStock | 3385 | RF ANTENNA 2.4G Surface Mount 1206

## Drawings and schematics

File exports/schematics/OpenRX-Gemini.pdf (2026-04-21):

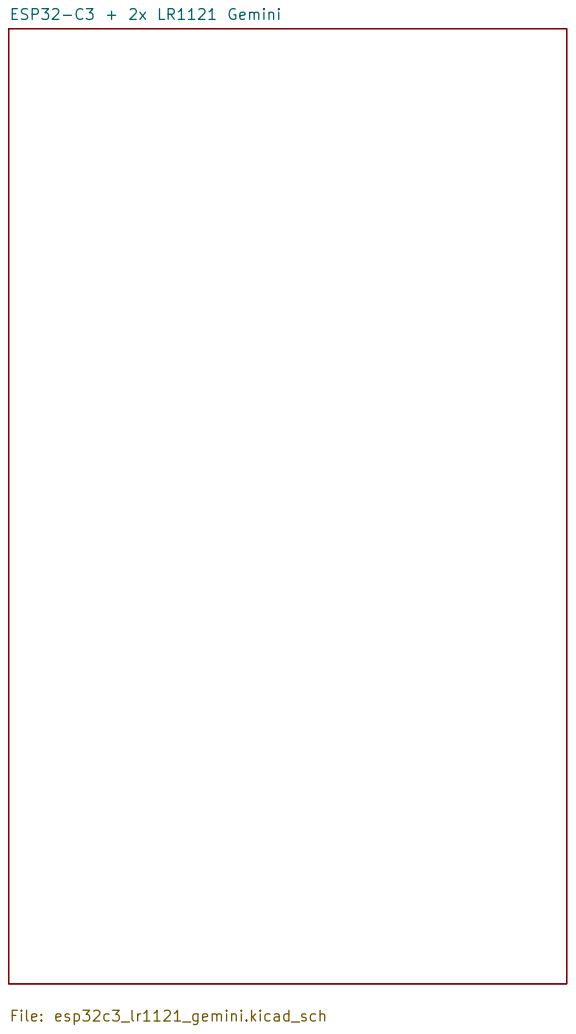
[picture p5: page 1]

Size: A3 | Rev: | F Date:
KiCad E.D.A. 10.0.0 | Id: 1/2

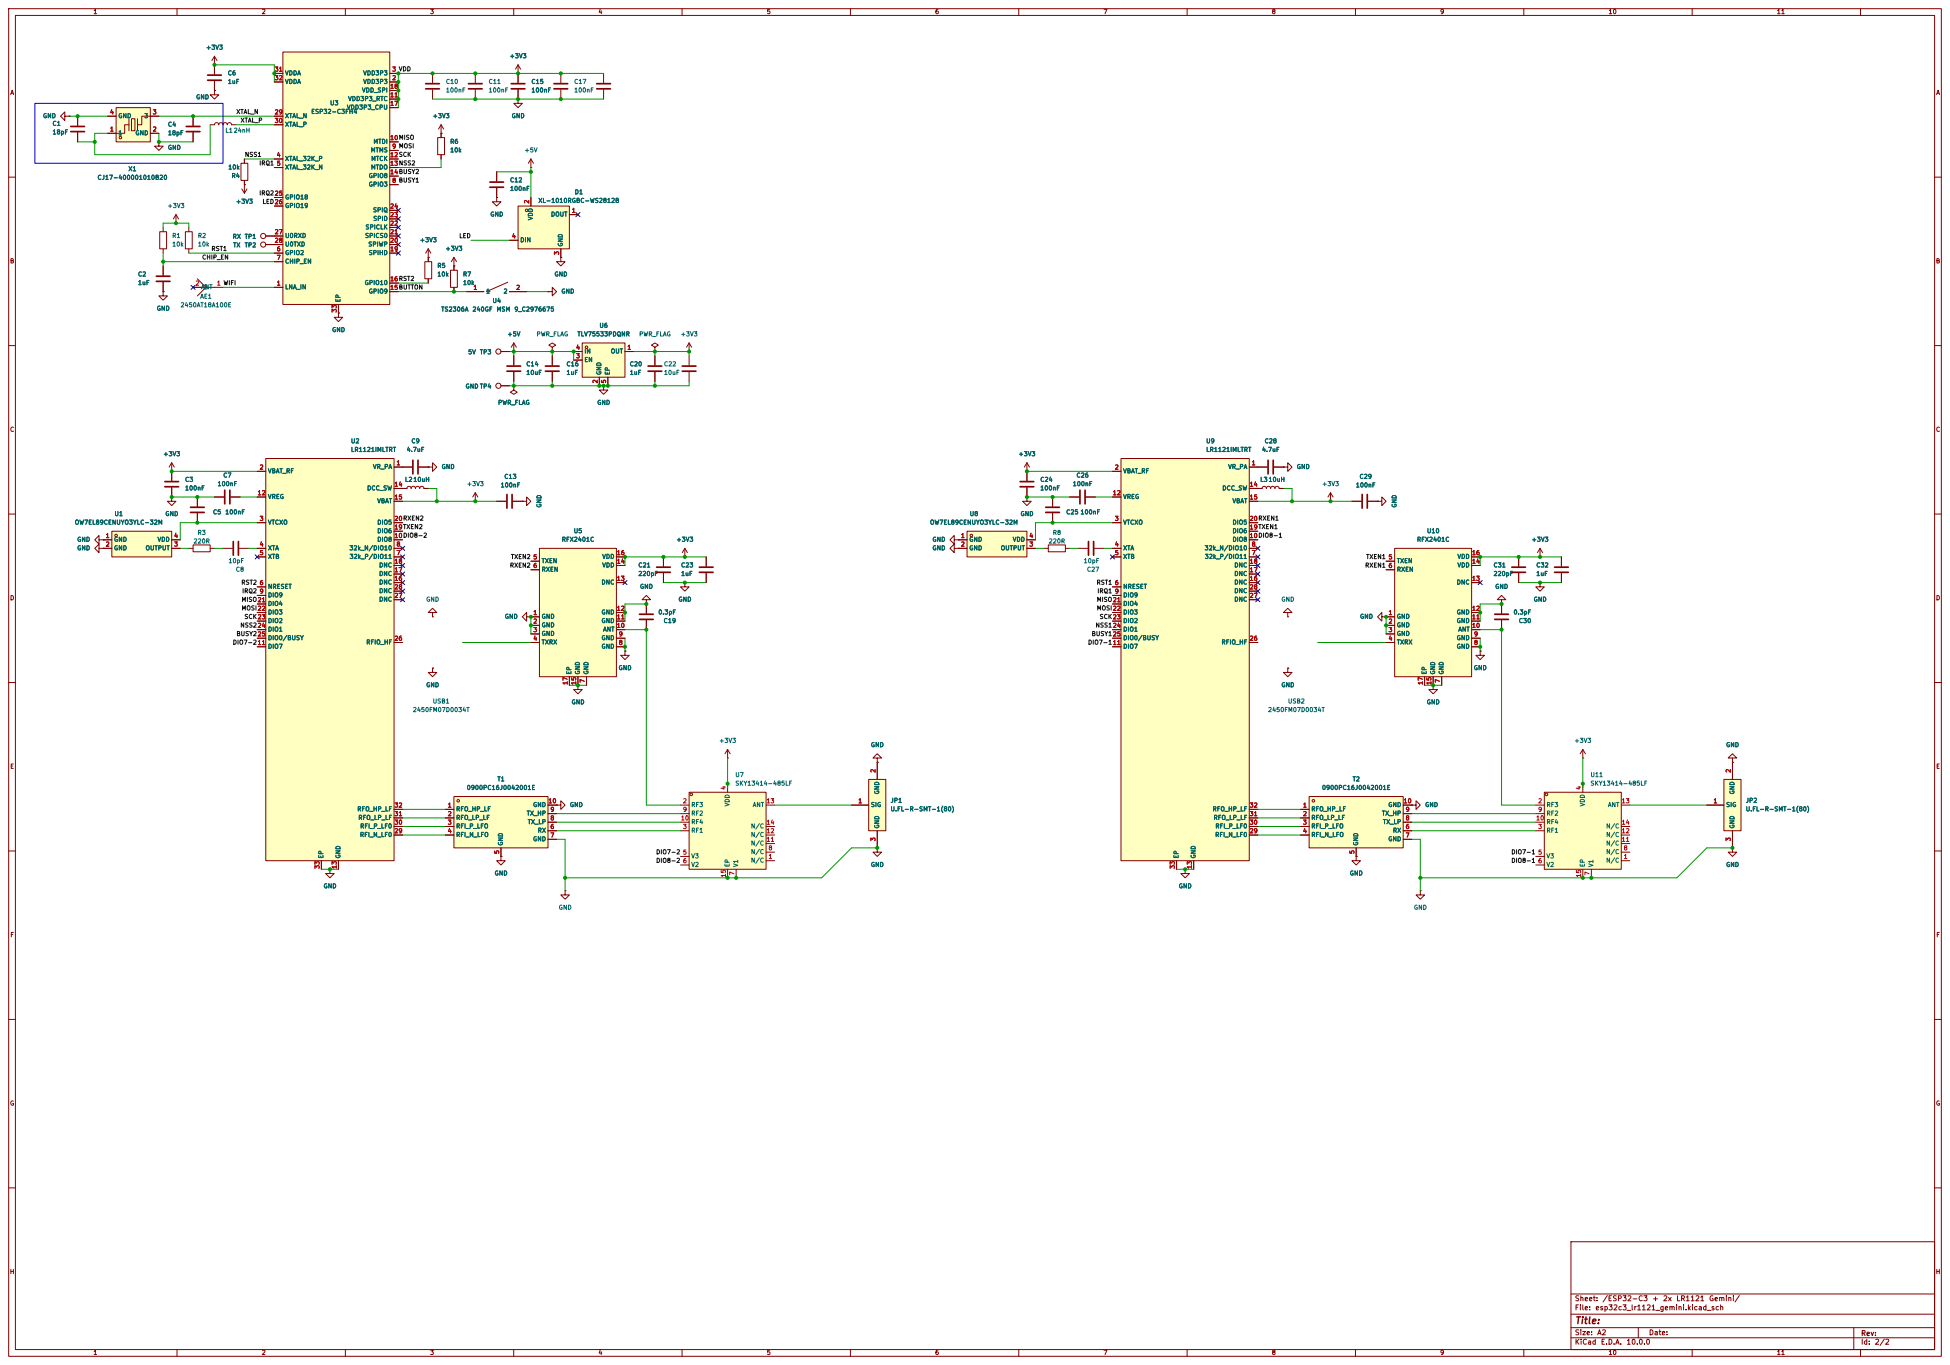
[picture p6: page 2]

Size: A2 | Rev:
KiCad E.D.A. 10.0.0 | Id: 2/2

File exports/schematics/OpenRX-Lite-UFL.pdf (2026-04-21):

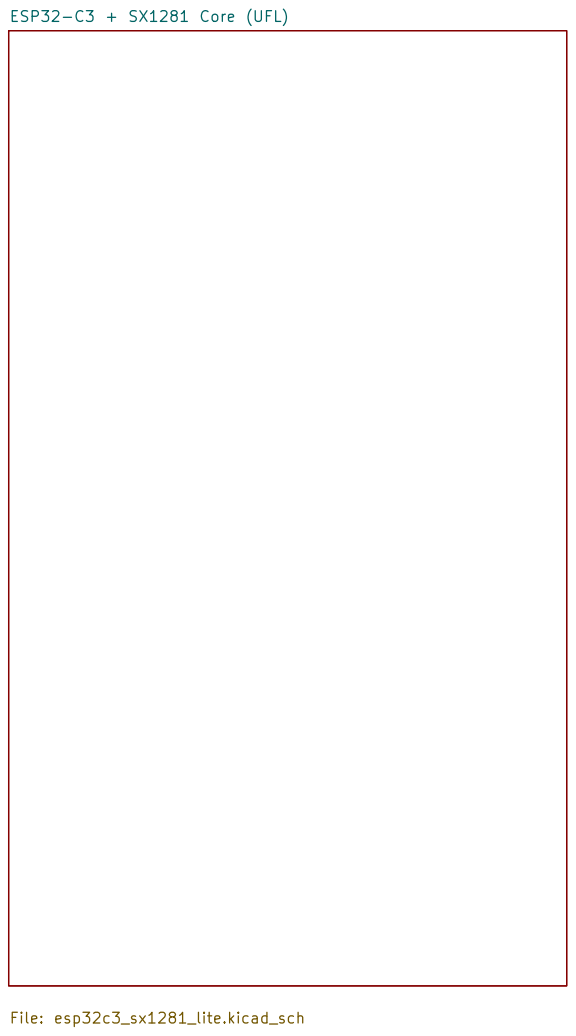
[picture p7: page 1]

Sheet: /
File: OpenRX-Lite-UFL.kicad_sch
Title:

Size: A3 | Rev: | F Date:
KiCad E.D.A. 10.0.0 | Id: 1/2

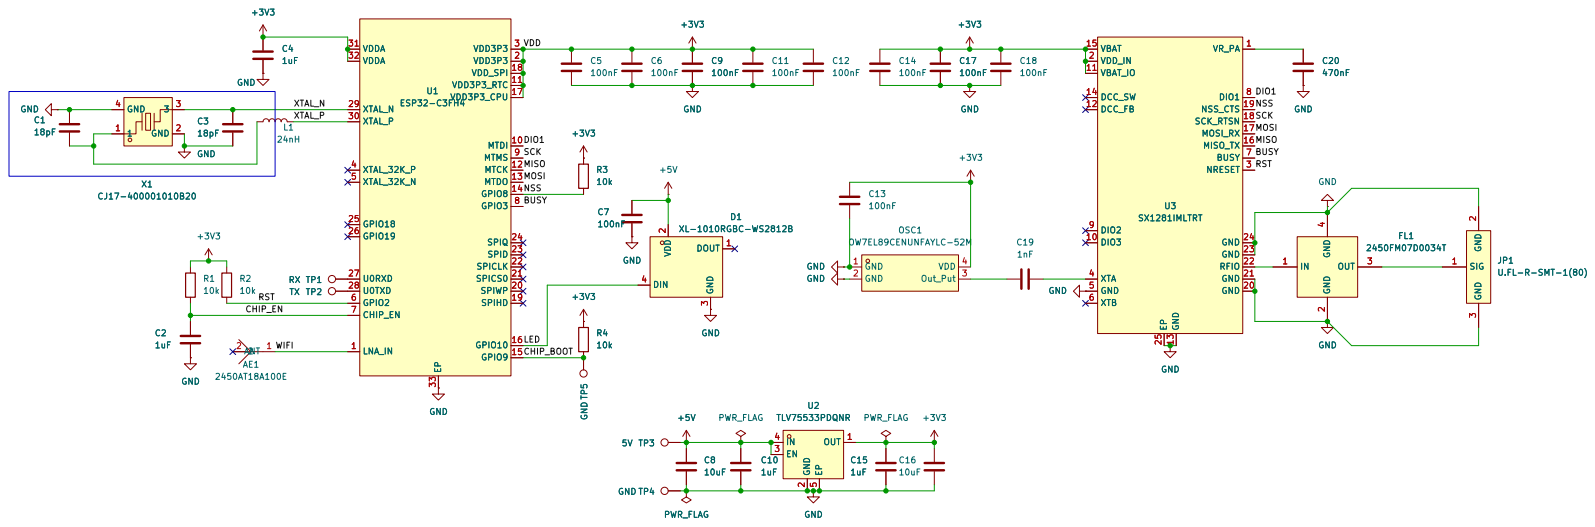
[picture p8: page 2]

Size: A3 | Rev: | F Date:
KiCad E.D.A. 10.0.0 | Id: 2/2

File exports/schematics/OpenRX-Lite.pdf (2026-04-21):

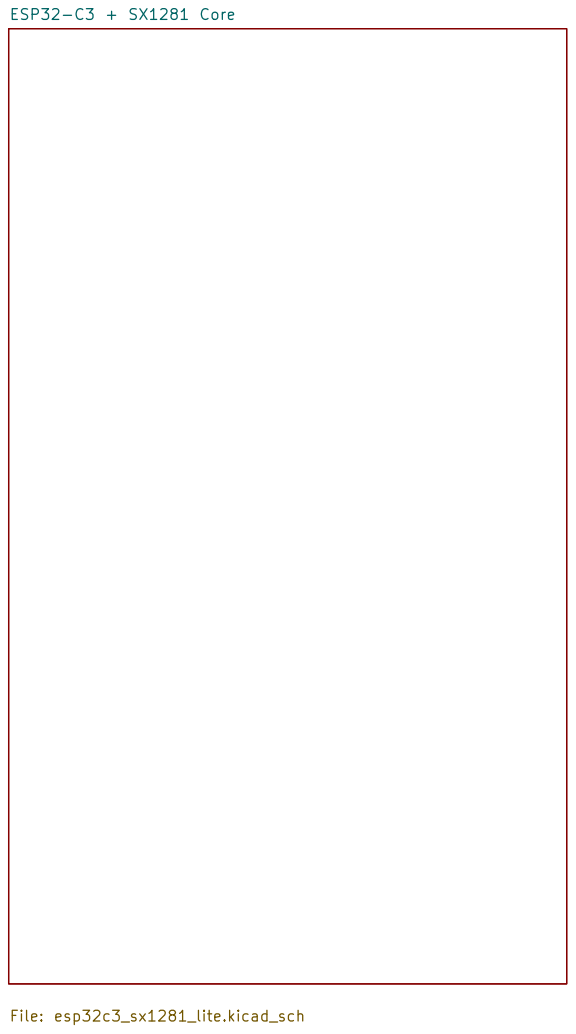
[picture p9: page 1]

Size: A3 | Rev: | F Date:
KiCad E.D.A. 10.0.0 | Id: 1/2

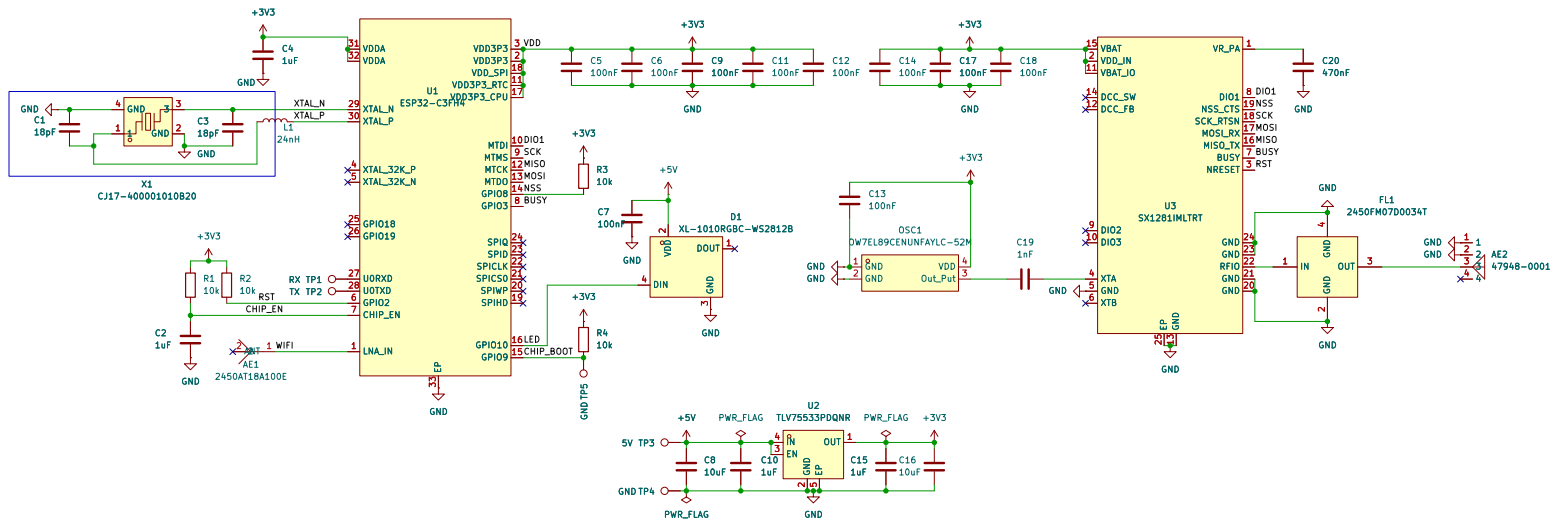
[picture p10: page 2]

RST BUSY MISO MOSI VDD

Size: A3 | Rev: | F Date:
KiCad E.D.A. 10.0.0 | Id: 2/2

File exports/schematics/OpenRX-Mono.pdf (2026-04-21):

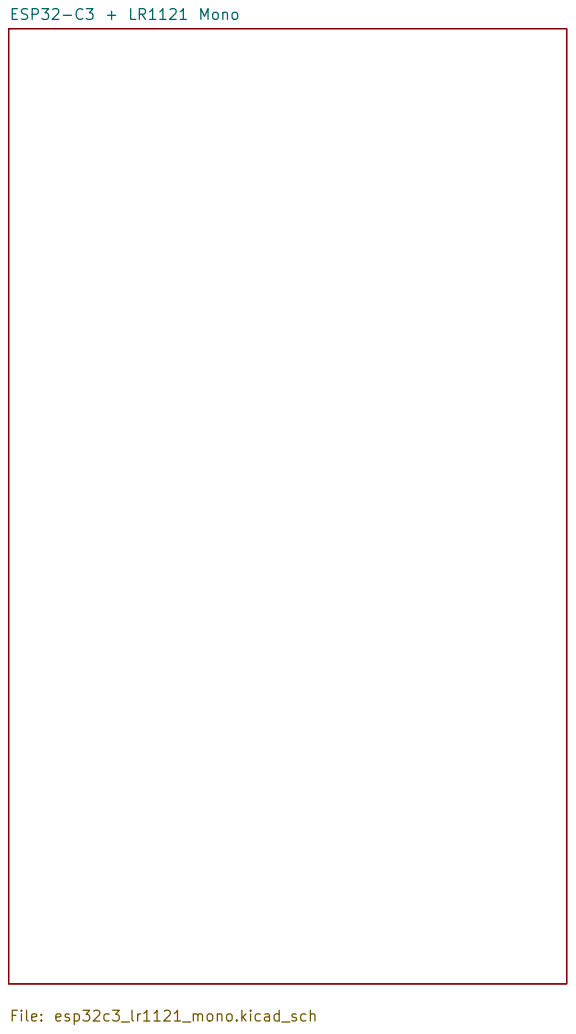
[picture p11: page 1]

Size: A3 | Rev: | F Date:
KiCad E.D.A. 10.0.0 | Id: 1/2

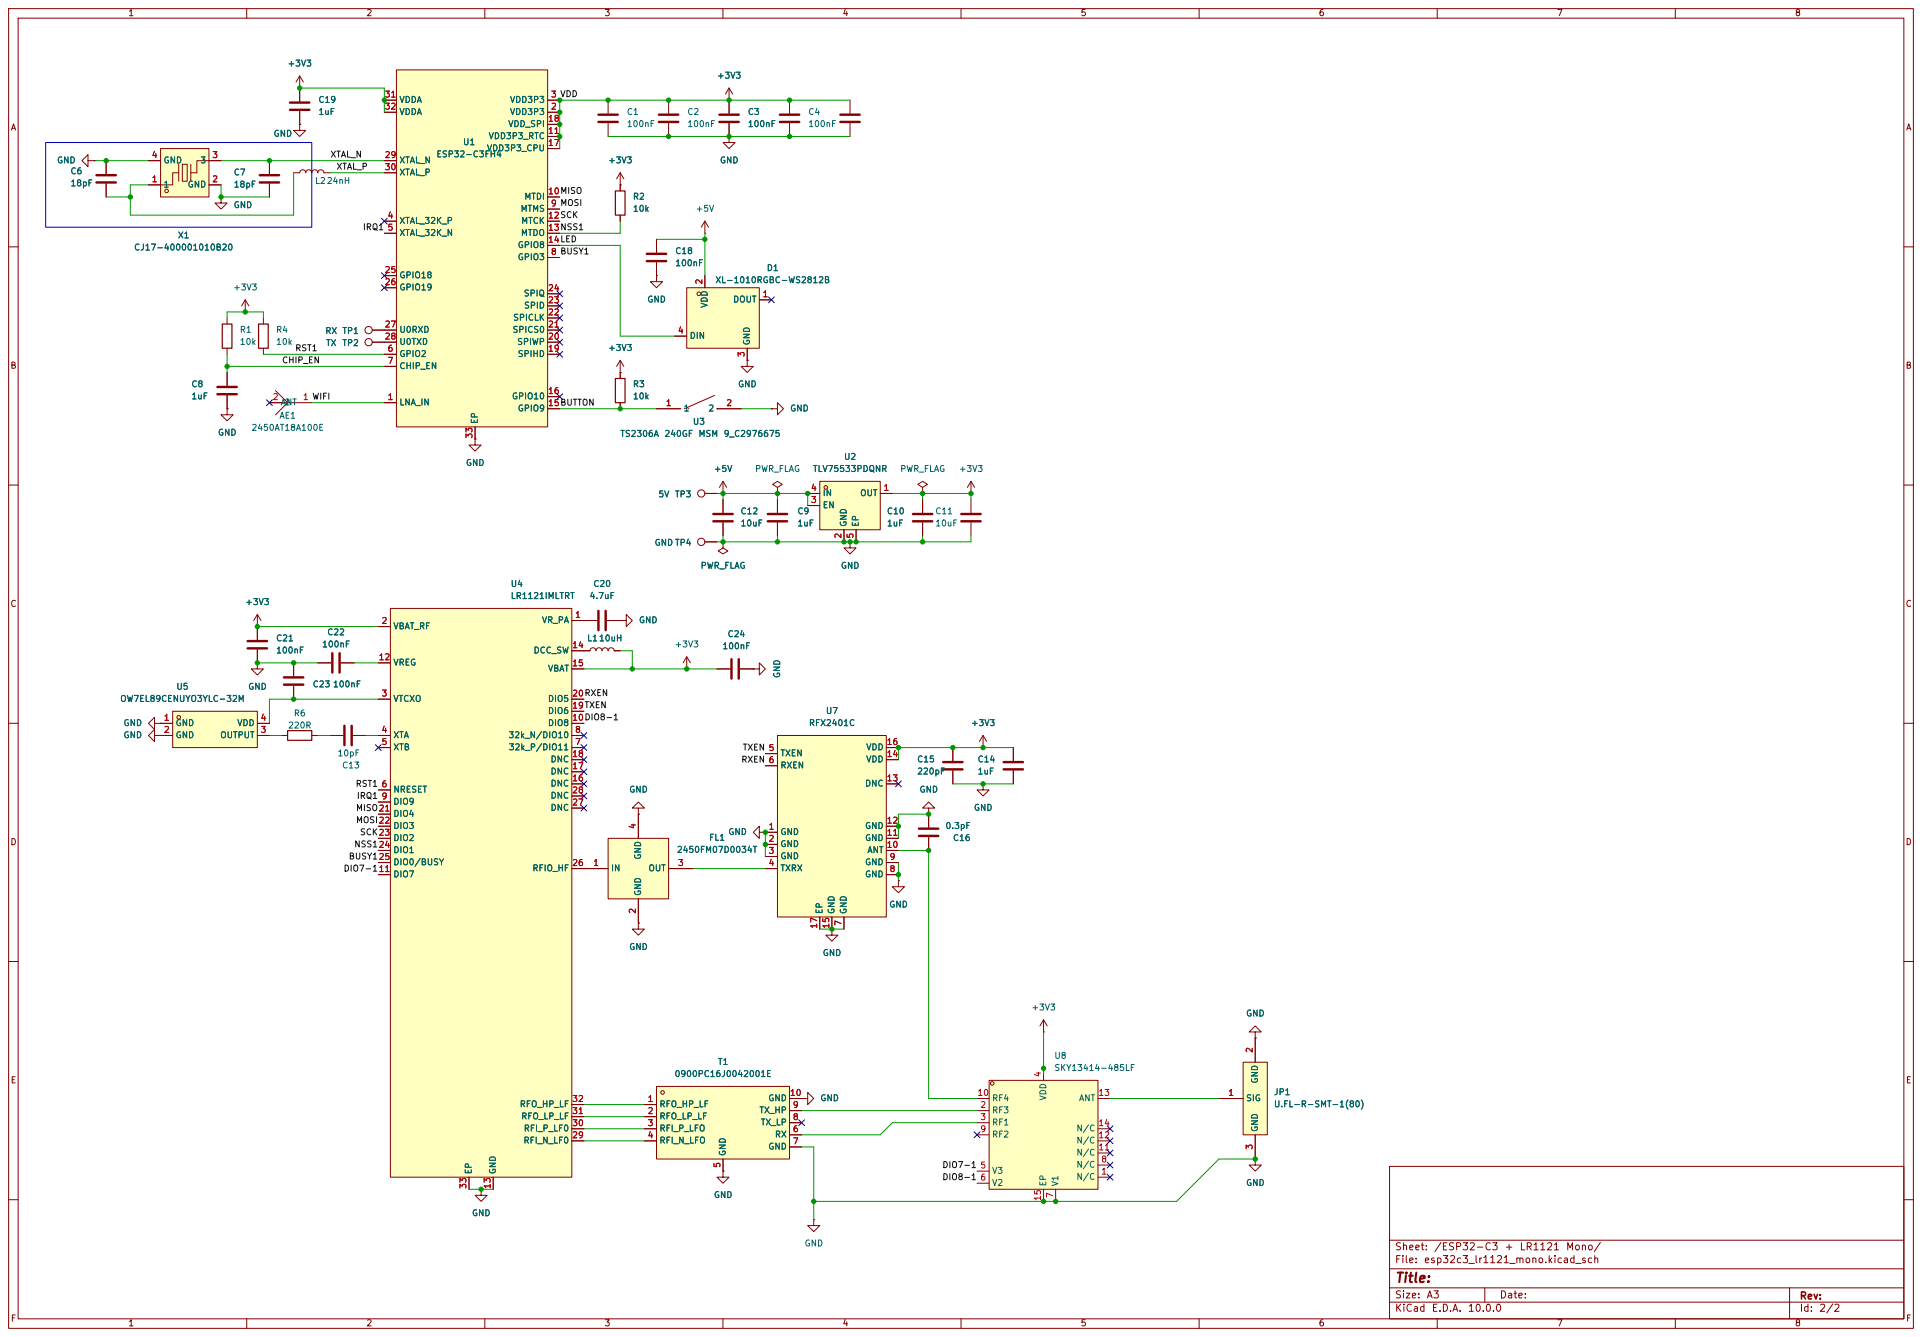
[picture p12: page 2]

Size: A3 | Rev:
KiCad E.D.A. 10.0.0 | Id: 2/2

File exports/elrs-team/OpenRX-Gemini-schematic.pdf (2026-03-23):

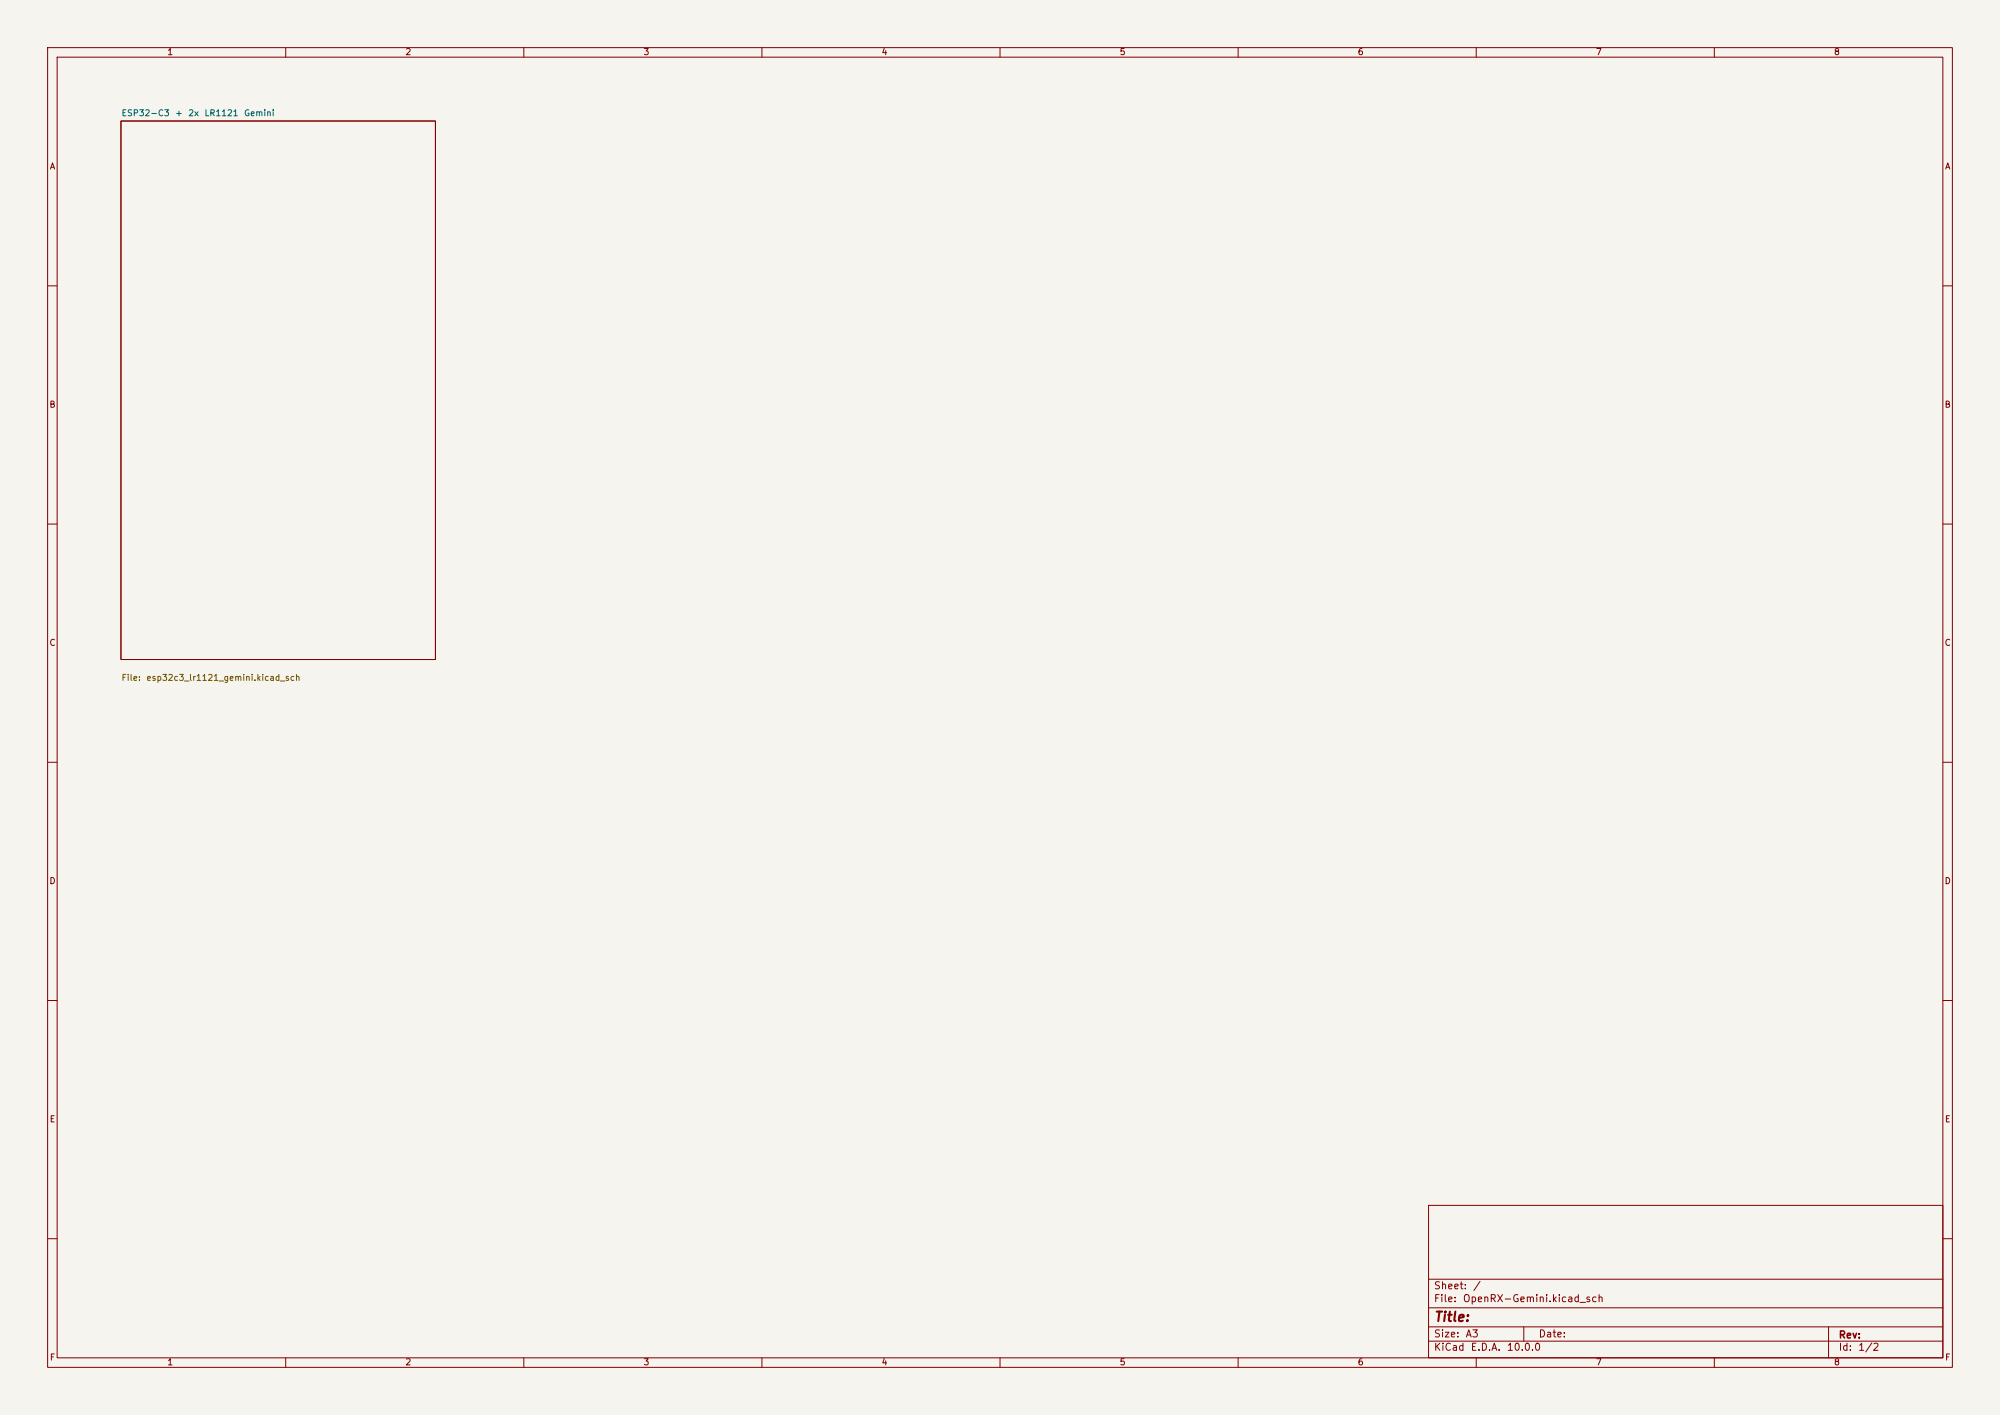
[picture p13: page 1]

Size: A3 | Rev: | F Date:
KiCad E.D.A. 10.0.0 | Id: 1/2

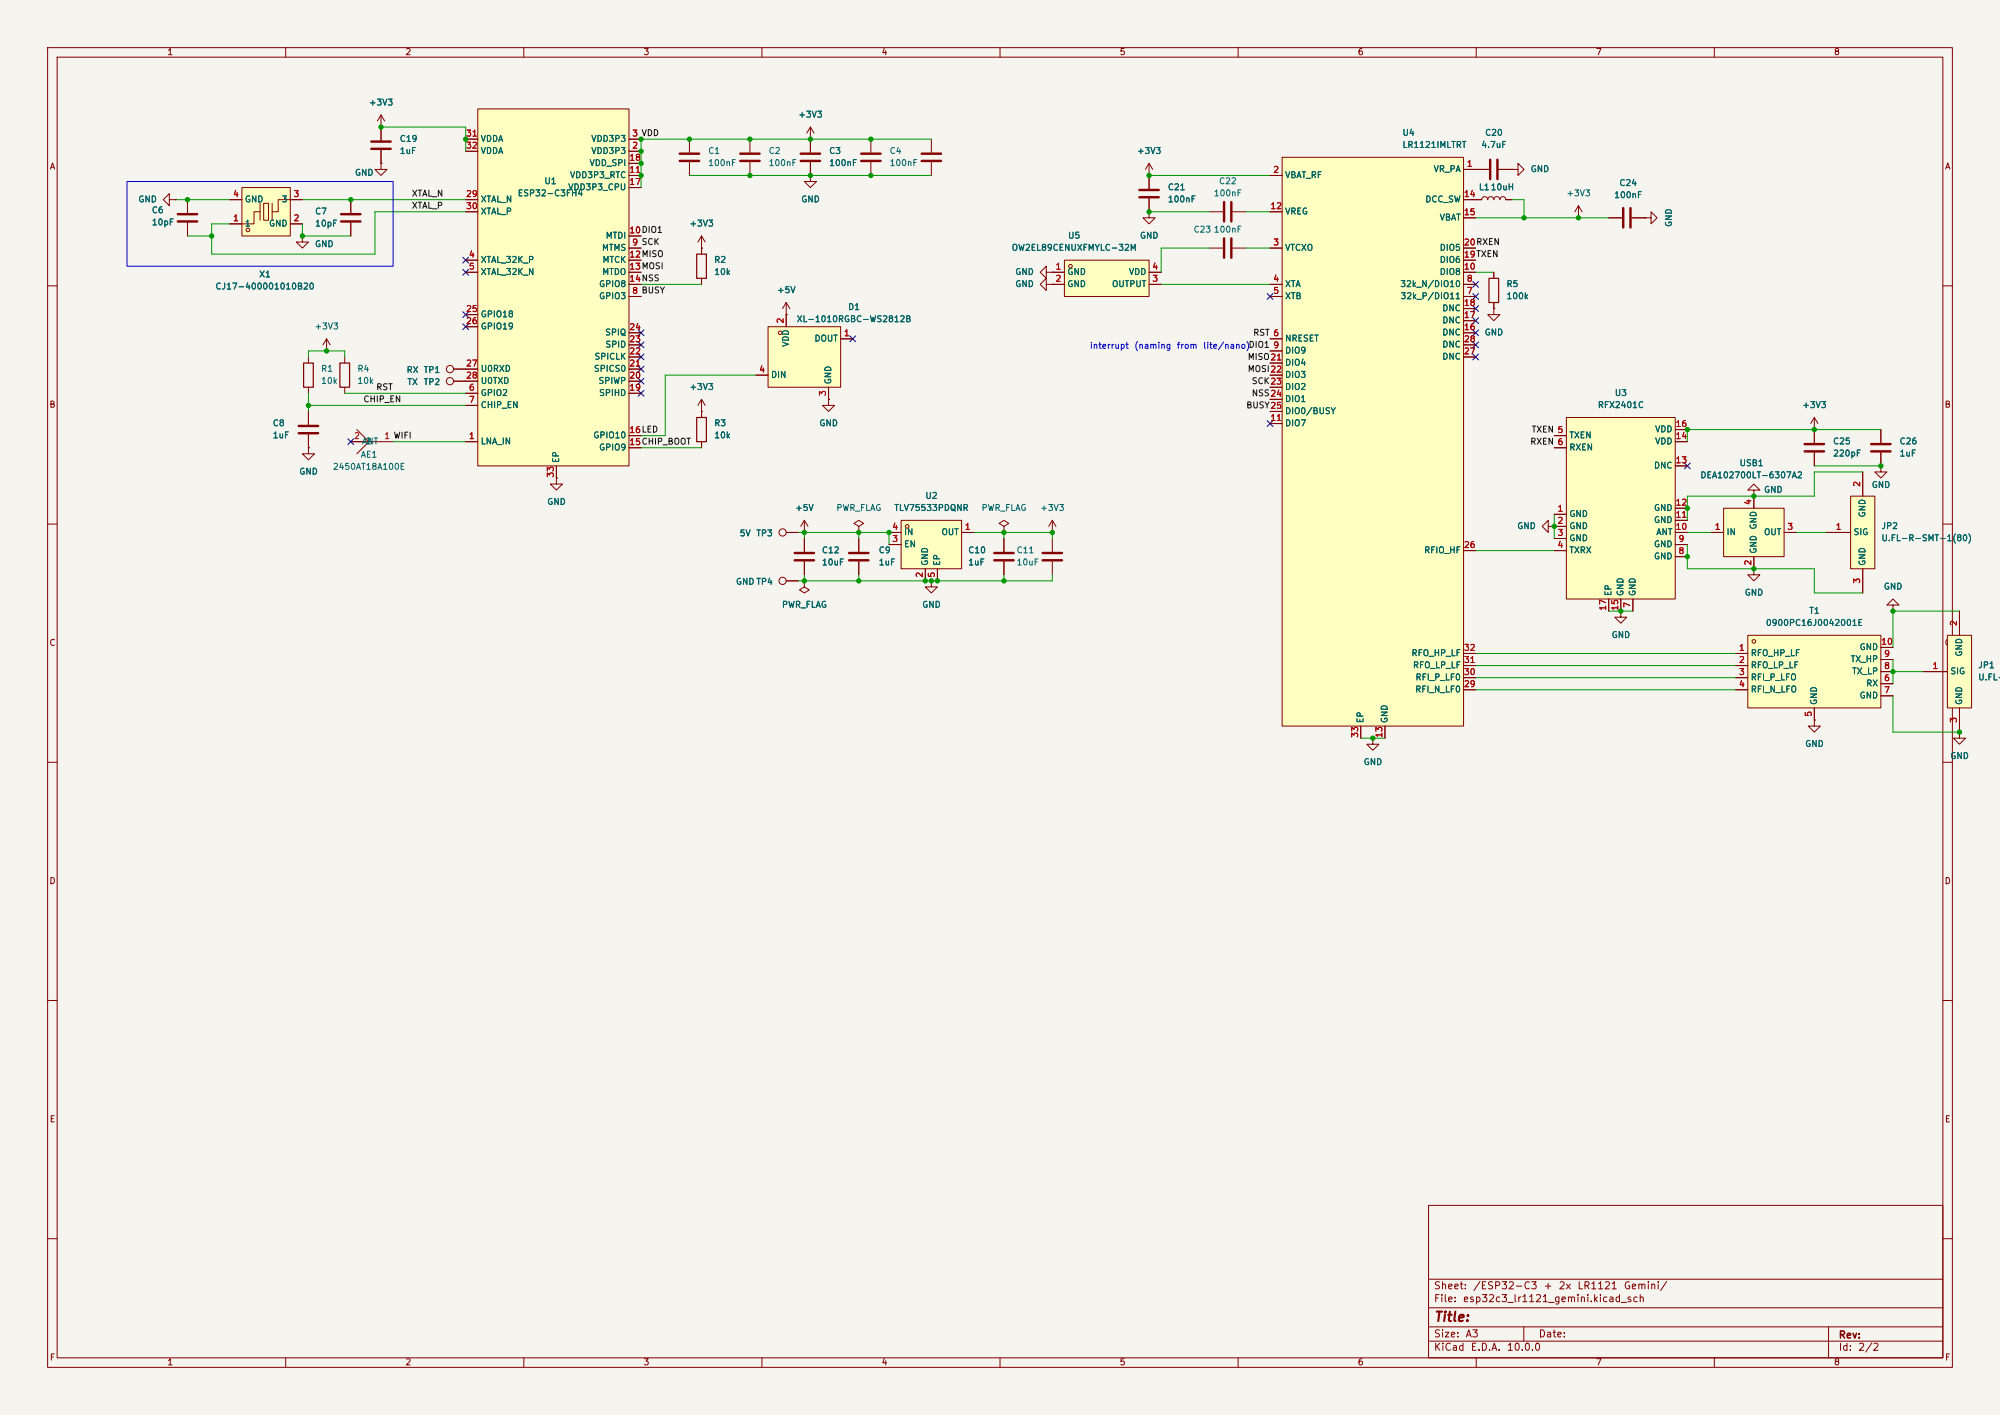
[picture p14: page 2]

interrupt (naming from lite/nano) C7

RXEN MOSI RST MISO

Size: A3 | Rev: | F Date:
KiCad E.D.A. 10.0.0 | Id: 2/2

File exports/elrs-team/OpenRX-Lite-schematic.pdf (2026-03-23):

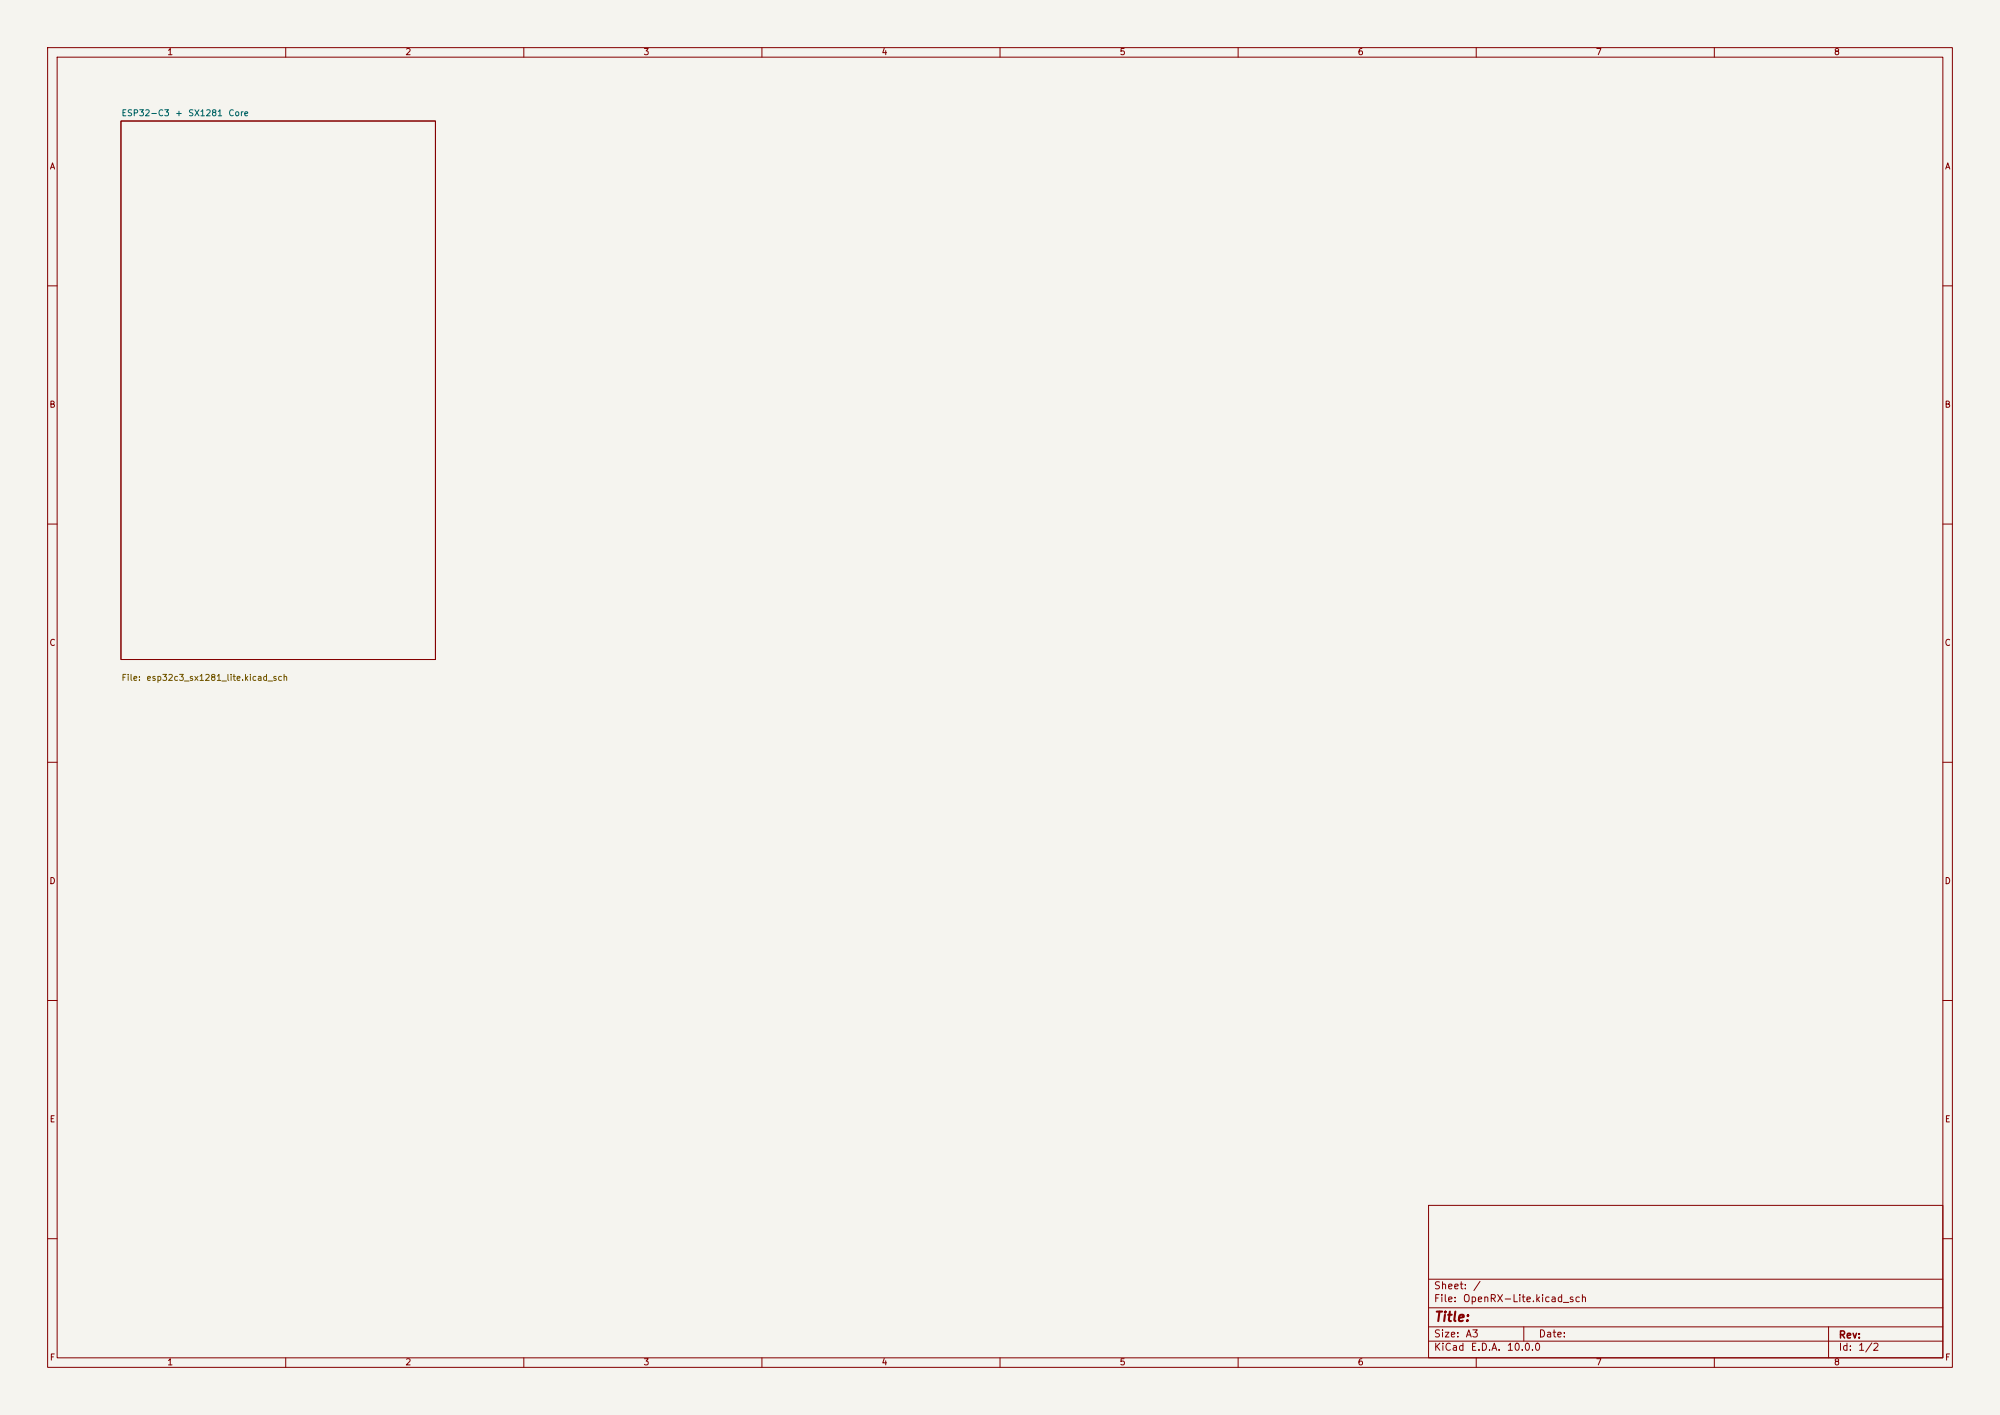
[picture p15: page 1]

Size: A3 | Rev: | F Date:
KiCad E.D.A. 10.0.0 | Id: 1/2

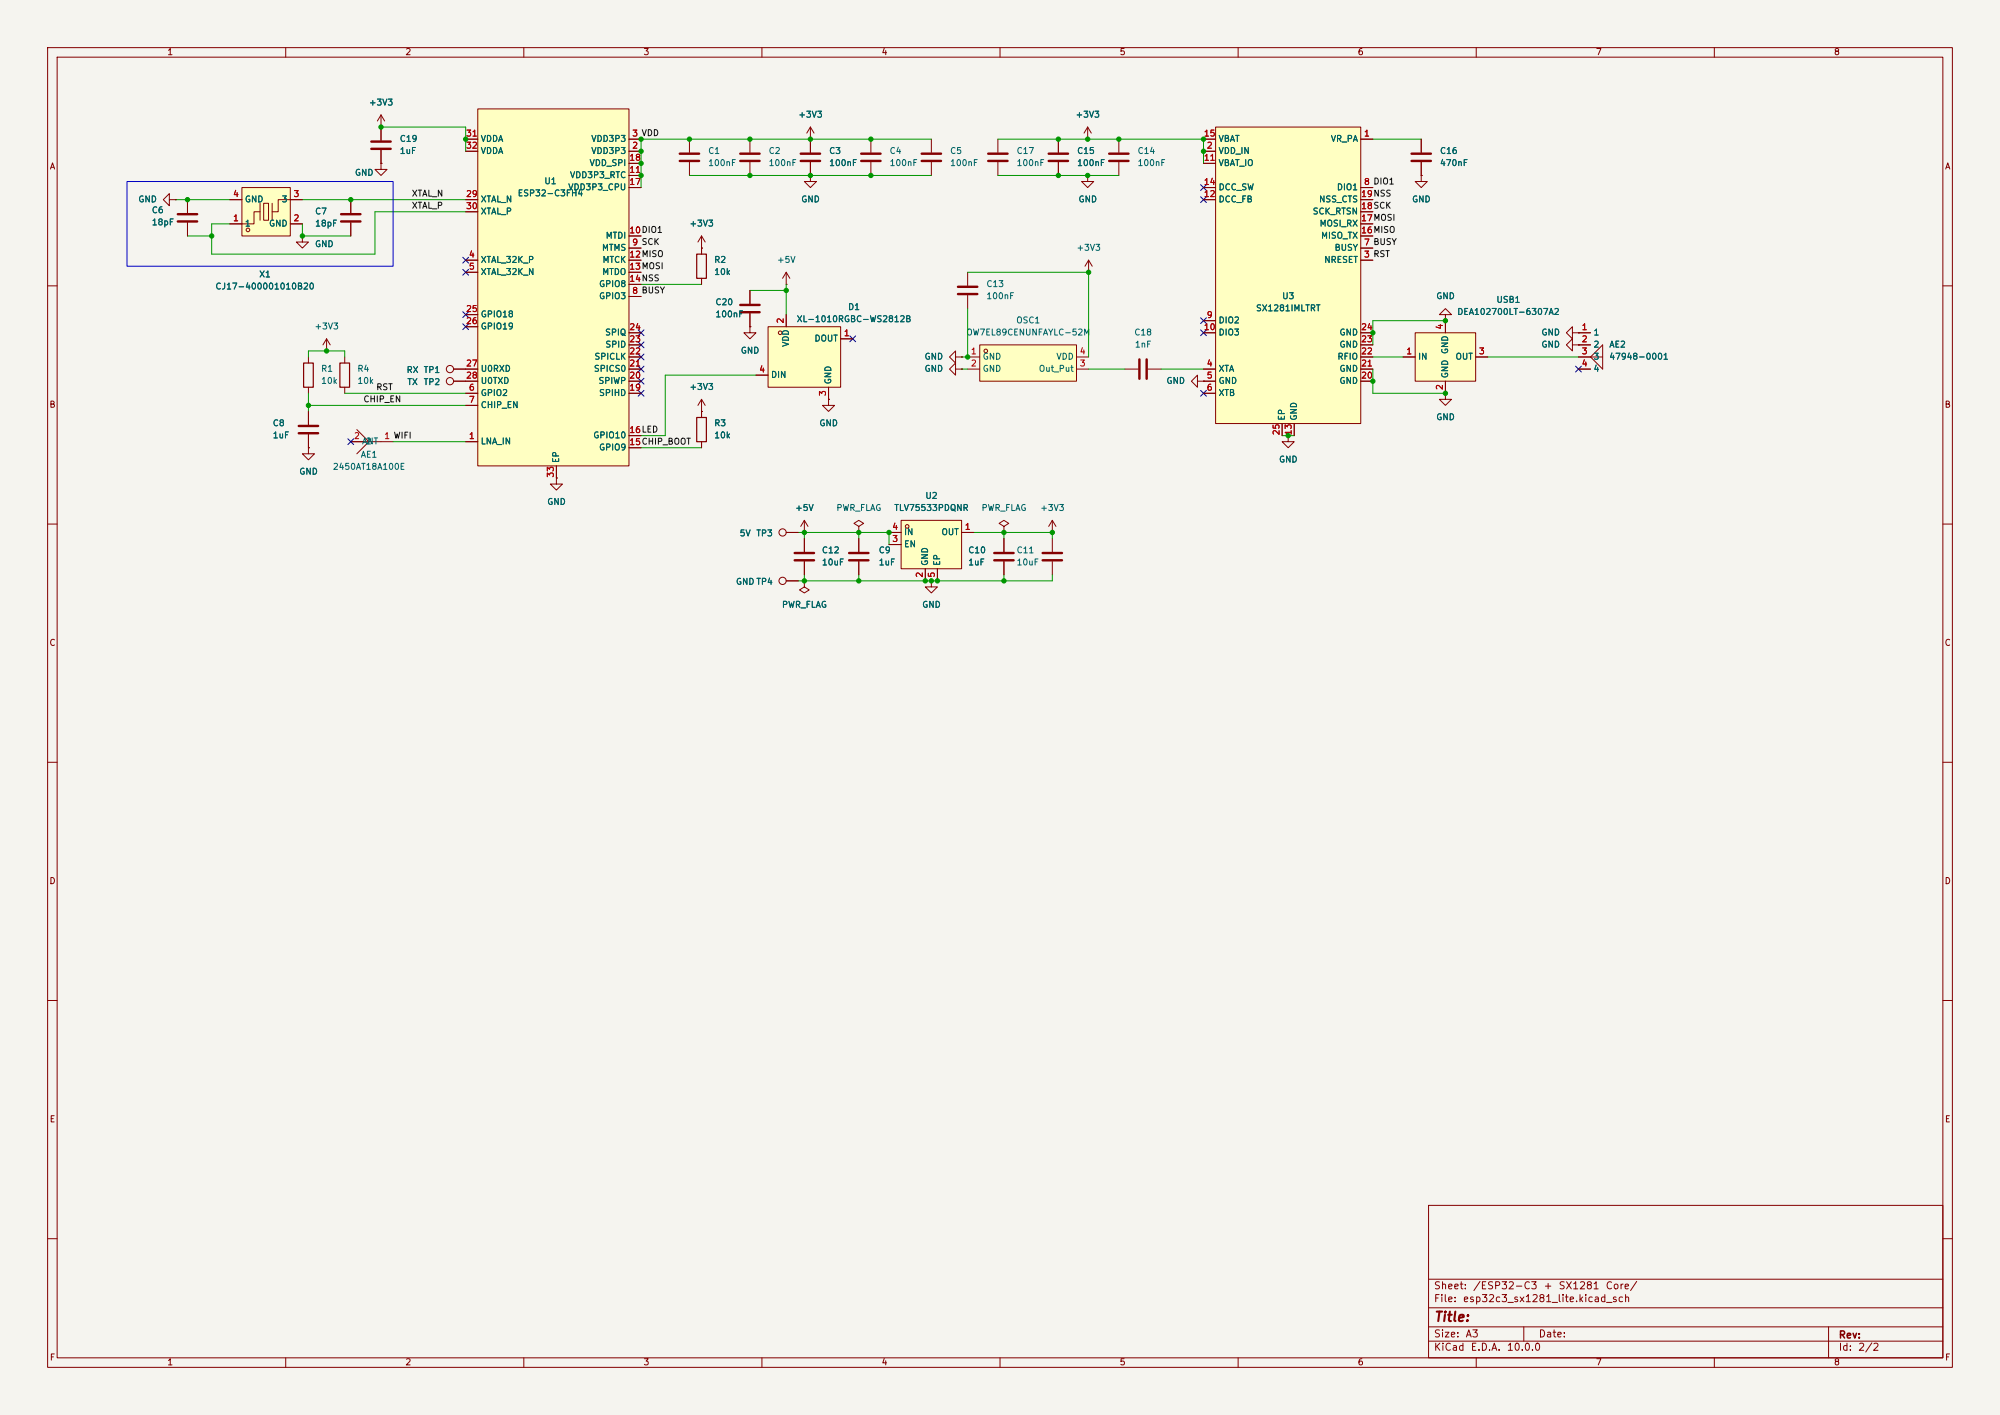
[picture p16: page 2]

Size: A3 | Rev: | F Date:
KiCad E.D.A. 10.0.0 | Id: 2/2

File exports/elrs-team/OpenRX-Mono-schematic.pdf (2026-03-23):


Size: A3 | Rev: | F Date:
KiCad E.D.A. 10.0.0 | Id: 1/2


interrupt (naming from lite/nano) C7

Size: A3 | Rev: | F Date:
KiCad E.D.A. 10.0.0 | Id: 2/2

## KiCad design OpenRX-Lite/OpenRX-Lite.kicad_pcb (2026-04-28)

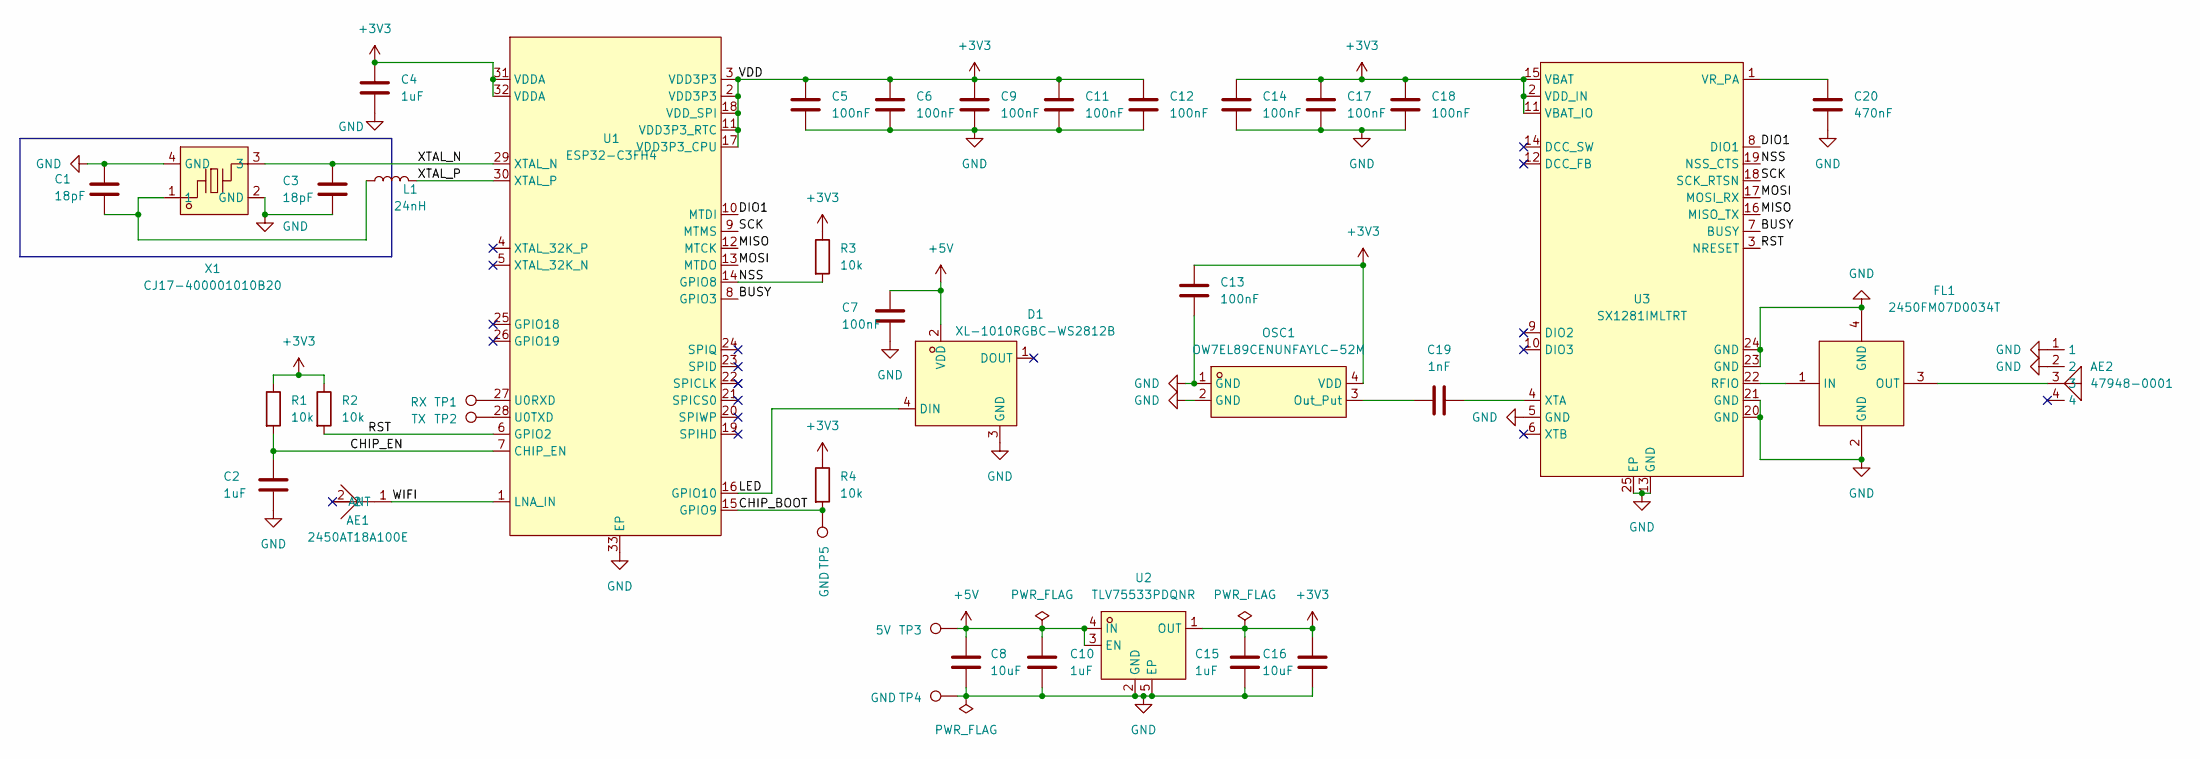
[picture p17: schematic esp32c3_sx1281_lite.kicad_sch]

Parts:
AE1: 2450AT18A100E; ANT-SMD_L3.2-W1.6; LCSC Part C89334
AE2: 47948-0001; ANT-SMD_47948-0001; LCSC Part C152351
C1, C3: 18pF; C_0201_0603Metric; LCSC C62164
C2, C4, C10, C15: 1uF; C_0201_0603Metric; LCSC C76935
C5, C6, C7, C9, C11, C12, C13, C14, C17, C18: 100nF; C_0201_0603Metric; LCSC C76939
C8, C16: 10uF; C_0402_1005Metric; LCSC C15525
C19: 1nF; C_0201_0603Metric; LCSC C66942
C20: 470nF; C_0201_0603Metric; LCSC C85926
D1: XL-1010RGBC-WS2812B; LED-SMD_4P-L1.0-W1.0-TL_XL-1010RGBC-WS2812B; LCSC Part C5349953
FL1: 2450FM07D0034T; FILTER-SMD_4P-L1.0-W0.5-L; MPN 2450FM07D0034T; LCSC Part C2651081
L1: 24nH; L_0201_0603Metric; LCSC C206441
OSC1: OW7EL89CENUNFAYLC-52M; OSC-SMD_4P-L2.0-W1.6-BL_TXC_7Z; LCSC Part C22434896
R1, R2, R3, R4: 10k; R_0201_0603Metric; LCSC C106225
TP1: RX; SolderPad_1.2x2.0mm
TP2: TX; SolderPad_1.2x2.0mm
TP3: 5V; SolderPad_1.2x2.0mm
TP4, TP5: GND; SolderPad_1.2x2.0mm
U1: ESP32-C3FH4; QFN-32_L5.0-W5.0-P0.50-TL-EP3.7; LCSC Part C2858491
U2: TLV75533PDQNR; X2SON-4_L1.0-W1.0-P0.65-TL-EP; LCSC Part C2861882
U3: SX1281IMLTRT; QFN-24_L4.0-W4.0-P0.50-TL-EP2.6; LCSC Part C2151551
X1: CJ17-400001010B20; CRYSTAL-SMD_4P-L1.6-W1.2-BL; LCSC Part C2875272

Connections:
+3V3: C4.1, C5.1, C6.1, C9.1, C11.1, C12.1, C13.1, C14.1, C15.1, C16.1, C17.1, C18.1, OSC1.4 (VDD), R1.1, R2.1, R3.1, R4.1, U1.2 (VDD3P3), U1.3 (VDD3P3), U1.11 (VDD3P3_RTC), U1.17 (VDD3P3_CPU), U1.18 (VDD_SPI), U1.31 (VDDA), U1.32 (VDDA), U2.1 (OUT), U3.2 (VDD_IN), U3.11 (VBAT_IO), U3.15 (VBAT)
+5V: C7.1, C8.1, C10.1, D1.2 (VDD), TP3.1 (1_1), U2.3 (EN), U2.4 (IN)
/ESP32-C3 + SX1281 Core/BUSY: U1.8 (GPIO3), U3.7 (BUSY)
/ESP32-C3 + SX1281 Core/CHIP_BOOT: R4.2, TP5.1 (1_1), U1.15 (GPIO9)
/ESP32-C3 + SX1281 Core/CHIP_EN: C2.1, R1.2, U1.7 (CHIP_EN)
/ESP32-C3 + SX1281 Core/DIO1: U1.10 (MTDI), U3.8 (DIO1)
/ESP32-C3 + SX1281 Core/LED: D1.4 (DIN), U1.16 (GPIO10)
/ESP32-C3 + SX1281 Core/MISO: U1.12 (MTCK), U3.16 (MISO_TX)
/ESP32-C3 + SX1281 Core/MOSI: U1.13 (MTDO), U3.17 (MOSI_RX)
/ESP32-C3 + SX1281 Core/NSS: R3.2, U1.14 (GPIO8), U3.19 (NSS_CTS)
/ESP32-C3 + SX1281 Core/RST: R2.2, U1.6 (GPIO2), U3.3 (NRESET)
/ESP32-C3 + SX1281 Core/SCK: U1.9 (MTMS), U3.18 (SCK_RTSN)
/ESP32-C3 + SX1281 Core/WIFI: AE1.1 (ANT_1), U1.1 (LNA_IN)
/ESP32-C3 + SX1281 Core/XTAL_N: C3.1, U1.29 (XTAL_N), X1.3
/ESP32-C3 + SX1281 Core/XTAL_P: L1.2, U1.30 (XTAL_P)
GND: AE2.1, AE2.2, C1.2, C2.2, C3.2, C4.2, C5.2, C6.2, C7.2, C8.2, C9.2, C10.2, C11.2, C12.2, C13.2, C14.2, C15.2, C16.2, C17.2, C18.2, C20.2, D1.3 (GND), FL1.2 (GND), FL1.4 (GND), OSC1.1 (GND), OSC1.2 (GND), TP4.1 (1_1), U1.33 (EP), U2.2 (GND), U2.5 (EP), U3.5 (GND), U3.13 (GND), U3.20 (GND), U3.21 (GND), U3.23 (GND), U3.24 (GND), U3.25 (EP), X1.2 (GND), X1.4 (GND)
unnamed: C1.1, L1.1, X1.1
unnamed: FL1.1 (IN), U3.22 (RFIO)
unnamed: AE2.3, FL1.3 (OUT)
unnamed: C19.1, OSC1.3 (Out_Put)
unnamed: TP1.1 (1_1), U1.27 (U0RXD)
unnamed: TP2.1 (1_1), U1.28 (U0TXD)
unnamed: C20.1, U3.1 (VR_PA)
unnamed: C19.2, U3.4 (XTA)

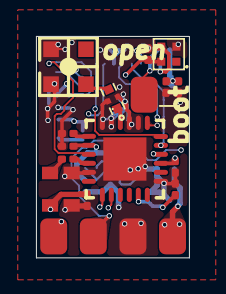
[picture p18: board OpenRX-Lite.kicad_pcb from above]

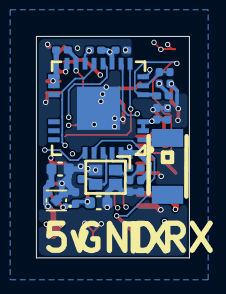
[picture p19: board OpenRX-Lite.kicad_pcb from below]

Board: 6 copper layers, 8.5 x 12.3 mm, 39 parts (20 on the bottom side), 24 nets.

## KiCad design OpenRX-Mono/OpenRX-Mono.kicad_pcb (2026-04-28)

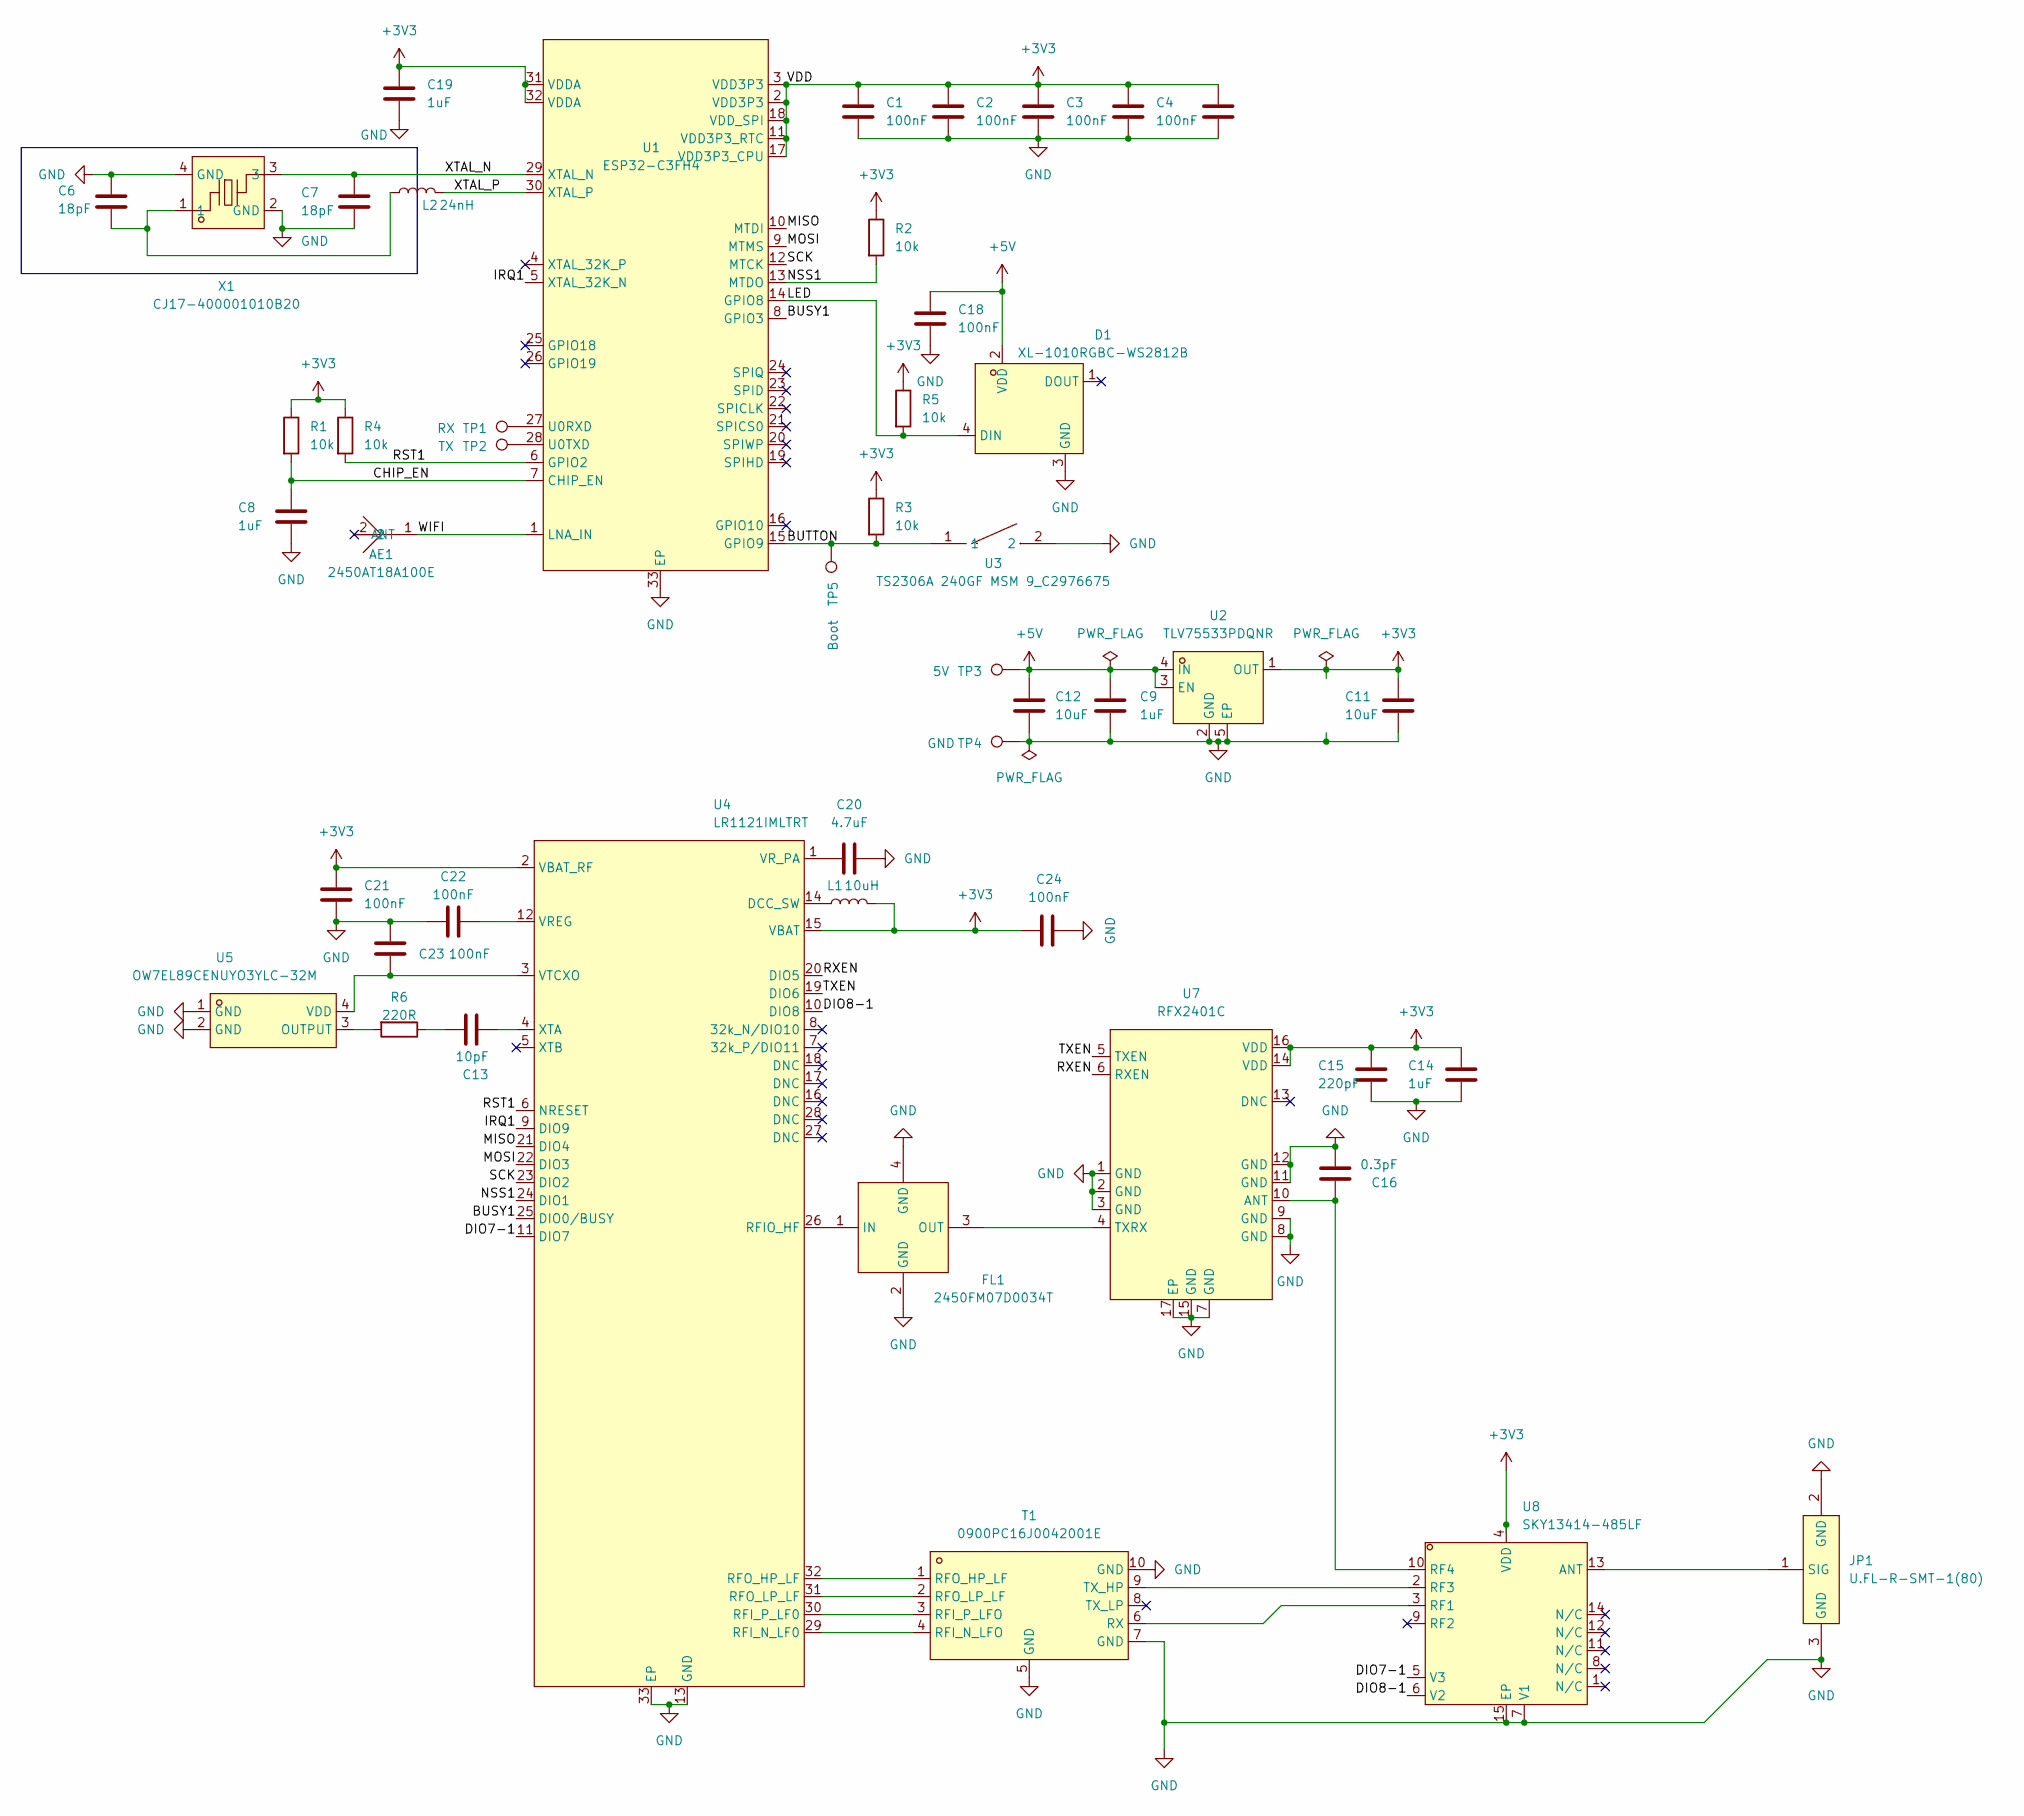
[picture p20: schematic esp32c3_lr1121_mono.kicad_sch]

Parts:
AE1: 2450AT18A100E; ANT-SMD_L3.2-W1.6; LCSC Part C89334
C1, C2, C3, C4, C5, C18, C21, C22, C23, C24: 100nF; C_0201_0603Metric; LCSC C76939
C6, C7: 18pF; C_0201_0603Metric; LCSC C62164
C8, C9, C14, C19: 1uF; C_0201_0603Metric; LCSC C76935
C11, C12: 10uF; C_0402_1005Metric; LCSC C15525
C13: 10pF; C_0201_0603Metric; LCSC C76921
C15: 220pF; C_0201_0603Metric; LCSC C62548
C16: 0.3pF; C_0201_0603Metric; LCSC C76927
C20: 4.7uF; C_0402_1005Metric; LCSC C23733
D1: XL-1010RGBC-WS2812B; LED-SMD_4P-L1.0-W1.0-TL_XL-1010RGBC-WS2812B; LCSC Part C5349953
FL1: 2450FM07D0034T; FILTER-SMD_4P-L1.0-W0.5-L; MPN 2450FM07D0034T; LCSC Part C2651081
JP1: U.FL-R-SMT-1(80); RF-SMD_FRF05002-JSS103M; LCSC Part C88374
L1: 10uH; L_0603_1608Metric; LCSC C1035
L2: 24nH; L_0201_0603Metric; LCSC C206441
R1, R2, R3, R4, R5: 10k; R_0201_0603Metric; LCSC C106225
R6: 220R; R_0201_0603Metric; LCSC C274342
T1: 0900PC16J0042001E; FILTER-SMD_10P-L2.0-W1.6-BL; LCSC Part C19842466
TP1: RX; SolderPad_1.2x2.0mm
TP2: TX; SolderPad_1.2x2.0mm
TP3: 5V; SolderPad_1.2x2.0mm
TP4: GND; SolderPad_1.2x2.0mm
TP5: Boot; SolderPad_1.2x2.0mm
U1: ESP32-C3FH4; QFN-32_L5.0-W5.0-P0.50-TL-EP3.7; LCSC Part C2858491
U2: TLV75533PDQNR; X2SON-4_L1.0-W1.0-P0.65-TL-EP; LCSC Part C2861882
U3: TS2306A 240GF MSM 9_C2976675; SW-SMD_4P-L3.0-W2.0-P0.85-LS3.5; LCSC Part C2976675
U4: LR1121IMLTRT; QFN-32_L5.0-W5.0-P0.50-BL-EP3.7; LCSC Part C7498014
U5: OW7EL89CENUYO3YLC-32M; OSC-SMD_4P-L2.0-W1.6-BL_TXC_7Z; LCSC Part C22381772
U7: RFX2401C; QFN-16_L3.0-W3.0-P0.50-BL-EP1.7; LCSC Part C19213
U8: SKY13414-485LF; QFN-14_L2.0-W2.0-P0.45-BL-EP; MPN SKY13414-485LF; LCSC Part C255353
X1: CJ17-400001010B20; CRYSTAL-SMD_4P-L1.6-W1.2-BL; LCSC Part C2875272

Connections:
+3V3: C1.1, C2.1, C3.1, C4.1, C5.1, C11.1, C14.1, C15.1, C19.1, C21.1, C24.2, L1.2, R1.1, R2.1, R3.1, R4.1, R5.1, U1.2 (VDD3P3), U1.3 (VDD3P3), U1.11 (VDD3P3_RTC), U1.17 (VDD3P3_CPU), U1.18 (VDD_SPI), U1.31 (VDDA), U1.32 (VDDA), U2.1 (OUT), U4.2 (VBAT_RF), U4.15 (VBAT), U7.14 (VDD), U7.16 (VDD), U8.4 (VDD)
+5V: C9.1, C12.1, C18.1, D1.2 (VDD), TP3.1 (1_1), U2.3 (EN), U2.4 (IN)
/ESP32-C3 + LR1121 Mono/BUSY1: U1.8 (GPIO3), U4.25 (DIO0/BUSY)
/ESP32-C3 + LR1121 Mono/BUTTON: R3.2, TP5.1 (1_1), U1.15 (GPIO9), U3.1
/ESP32-C3 + LR1121 Mono/CHIP_EN: C8.1, R1.2, U1.7 (CHIP_EN)
/ESP32-C3 + LR1121 Mono/DIO7-1: U4.11 (DIO7), U8.5 (V3)
/ESP32-C3 + LR1121 Mono/DIO8-1: U4.10 (DIO8), U8.6 (V2)
/ESP32-C3 + LR1121 Mono/IRQ1: U1.5 (XTAL_32K_N), U4.9 (DIO9)
/ESP32-C3 + LR1121 Mono/LED: D1.4 (DIN), R5.2, U1.14 (GPIO8)
/ESP32-C3 + LR1121 Mono/MISO: U1.10 (MTDI), U4.21 (DIO4)
/ESP32-C3 + LR1121 Mono/MOSI: U1.9 (MTMS), U4.22 (DIO3)
/ESP32-C3 + LR1121 Mono/NSS1: R2.2, U1.13 (MTDO), U4.24 (DIO1)
/ESP32-C3 + LR1121 Mono/RST1: R4.2, U1.6 (GPIO2), U4.6 (NRESET)
/ESP32-C3 + LR1121 Mono/RXEN: U4.20 (DIO5), U7.6 (RXEN)
/ESP32-C3 + LR1121 Mono/SCK: U1.12 (MTCK), U4.23 (DIO2)
/ESP32-C3 + LR1121 Mono/TXEN: U4.19 (DIO6), U7.5 (TXEN)
/ESP32-C3 + LR1121 Mono/WIFI: AE1.1 (ANT_1), U1.1 (LNA_IN)
/ESP32-C3 + LR1121 Mono/XTAL_N: C7.1, U1.29 (XTAL_N), X1.3
/ESP32-C3 + LR1121 Mono/XTAL_P: L2.2, U1.30 (XTAL_P)
GND: C1.2, C2.2, C3.2, C4.2, C5.2, C6.2, C7.2, C8.2, C9.2, C11.2, C12.2, C14.2, C15.2, C16.2, C18.2, C19.2, C20.2, C21.2, C22.1, C23.1, C24.1, D1.3 (GND), FL1.2 (GND), FL1.4 (GND), JP1.2 (GND), JP1.3 (GND), T1.5 (GND), T1.7 (GND), T1.10 (GND), TP4.1 (1_1), U1.33 (EP), U2.2 (GND), U2.5 (EP), U3.2, U4.13 (GND), U4.33 (EP), U5.1 (GND), U5.2 (GND), U7.1 (GND), U7.2 (GND), U7.3 (GND), U7.7 (GND), U7.8 (GND), U7.9 (GND), U7.11 (GND), U7.12 (GND), U7.15 (GND), U7.17 (EP), U8.7 (V1), U8.15 (EP), X1.2 (GND), X1.4 (GND)
unnamed: C6.1, L2.1, X1.1
unnamed: C13.1, R6.1
unnamed: FL1.1 (IN), U4.26 (RFIO_HF)
unnamed: FL1.3 (OUT), U7.4 (TXRX)
unnamed: JP1.1 (SIG), U8.13 (ANT)
unnamed: T1.4 (RFI_N_LFO), U4.29 (RFI_N_LF0)
unnamed: T1.3 (RFI_P_LFO), U4.30 (RFI_P_LF0)
unnamed: T1.1 (RFO_HP_LF), U4.32 (RFO_HP_LF)
unnamed: T1.2 (RFO_LP_LF), U4.31 (RFO_LP_LF)
unnamed: T1.6 (RX), U8.3 (RF1)
unnamed: T1.9 (TX_HP), U8.2 (RF3)
unnamed: TP1.1 (1_1), U1.27 (U0RXD)
unnamed: TP2.1 (1_1), U1.28 (U0TXD)
unnamed: L1.1, U4.14 (DCC_SW)
unnamed: C22.2, U4.12 (VREG)
unnamed: C20.1, U4.1 (VR_PA)
unnamed: C23.2, U4.3 (VTCXO), U5.4 (VDD)
unnamed: C13.2, U4.4 (XTA)
unnamed: R6.2, U5.3 (OUTPUT)
unnamed: C16.1, U7.10 (ANT), U8.10 (RF4)

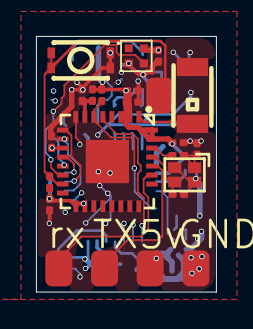
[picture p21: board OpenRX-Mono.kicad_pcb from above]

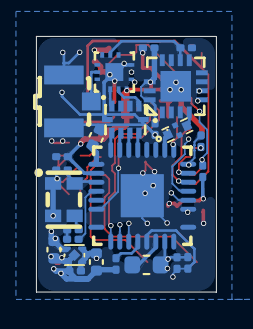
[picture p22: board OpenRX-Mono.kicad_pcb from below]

Board: 6 copper layers, 10.0 x 14.2 mm, 48 parts (25 on the bottom side), 40 nets.

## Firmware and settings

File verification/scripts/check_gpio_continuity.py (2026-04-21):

#!/usr/bin/env python3
"""
Verify schematic ↔ hardware.json continuity for each OpenRX board.

Source of truth: kicad-cli-exported netlist.xml next to each schematic.
Strategy:
  - Build ESP32-C3 pin-function → GPIO number table from the datasheet.
  - For the ESP32 component in the netlist, map each pinfunction to a GPIO.
  - Compare the GPIO numbers against the ELRS target JSON's declared pins.

Run after regenerating netlists:
  for d in OpenRX-Lite OpenRX-Lite-UFL OpenRX-Mono OpenRX-Gemini; do
    kicad-cli sch export netlist --format kicadxml \
        -o $d/netlist.xml $d/*core*.kicad_sch $d/esp32c3*.kicad_sch 2>/dev/null
  done
"""
from __future__ import annotations

import json
import os
import re
import sys
import xml.etree.ElementTree as ET

BASE = os.path.dirname(os.path.dirname(os.path.dirname(os.path.abspath(__file__))))
ELRS = os.path.join(BASE, "shared", "elrs-targets")

# ── ESP32-C3 (QFN32) pinfunction → GPIO# ───────────────────────────────
# Taken from the ESP32-C3 datasheet Table 3-2.
ESP32C3_PIN_TO_GPIO: dict[str, int] = {
    "XTAL_32K_P":  0,
    "XTAL_32K_N":  1,
    "GPIO2":       2,
    "GPIO3":       3,
    "MTMS":        4,
    "MTDI":        5,
    "MTCK":        6,
    "MTDO":        7,
    "GPIO8":       8,
    "GPIO9":       9,
    "GPIO10":      10,
    "VDD_SPI":     11,
    "SPIHD":       12,
    "SPIWP":       13,
    "SPICS0":      14,
    "SPICLK":      15,
    "SPID":        16,
    "SPIQ":        17,
    "GPIO18":      18,
    "GPIO19":      19,
    "U0RXD":       20,
    "U0TXD":       21,
}

# Net-name in schematic → ELRS JSON field. Uses a regex so the schematics
# are free to number signals per-radio (BUSY1, BUSY2, etc.) and we still
# find them.
NET_TO_FIELD_COMMON: list[tuple[re.Pattern[str], str]] = [
    (re.compile(r"^RX$"),           "serial_rx"),
    (re.compile(r"^TX$"),           "serial_tx"),
    (re.compile(r"^MOSI$"),         "radio_mosi"),
    (re.compile(r"^MISO$"),         "radio_miso"),
    (re.compile(r"^SCK$"),          "radio_sck"),
    (re.compile(r"^BUSY1?$"),       "radio_busy"),
    (re.compile(r"^IRQ1?$"),        "radio_dio1"),
    (re.compile(r"^NSS1?$"),        "radio_nss"),
    (re.compile(r"^RST1?$"),        "radio_rst"),
    (re.compile(r"^LED$"),          "led"),
    (re.compile(r"^LED$"),          "led_rgb"),  # Gemini uses RGB LED
    (re.compile(r"^BUTTON$|^BTN$"), "button"),
]

NET_TO_FIELD_RADIO_B: list[tuple[re.Pattern[str], str]] = [
    (re.compile(r"^BUSY2$"), "radio_busy_2"),
    (re.compile(r"^IRQ2$"),  "radio_dio1_2"),
    (re.compile(r"^NSS2$"),  "radio_nss_2"),
    (re.compile(r"^RST2$"),  "radio_rst_2"),
]


def parse_pinfunction(pinfunc: str) -> int | None:
    """Accept either 'GPIO3' or 'GPIO3_8' (<name>_<pin>) or 'MTDI_10'."""
    if not pinfunc:
        return None
    base = pinfunc.split("_")[0]
    # Some library variants expand: 'GPIO3' pin is GPIO3 directly
    if base in ESP32C3_PIN_TO_GPIO:
        return ESP32C3_PIN_TO_GPIO[base]
    # Handle 'XTAL_32K_P_4' style where base split was too aggressive
    m = re.match(r"(XTAL_32K_[PN])", pinfunc)
    if m:
        return ESP32C3_PIN_TO_GPIO[m.group(1)]
    return None


def gather_esp32_nets(netlist_xml: str) -> tuple[str, dict[str, int]]:
    """Return (esp_ref, {net_name_stripped: gpio#}) for the ESP32 on this netlist."""
    tree = ET.parse(netlist_xml)
    root = tree.getroot()

    esp_ref = None
    for comp in root.iter("comp"):
        if "ESP32" in comp.findtext("value", ""):
            esp_ref = comp.get("ref")
            break
    if not esp_ref:
        return "", {}

    out: dict[str, int] = {}
    for net in root.iter("net"):
        raw = net.get("name", "")
        name = raw.strip("/").split("/")[-1].upper()
        for node in net.iter("node"):
            if node.get("ref") != esp_ref:
                continue
            pinfunc = node.get("pinfunction") or ""
            gpio = parse_pinfunction(pinfunc)
            if gpio is not None:
                # Only record the first assignment for a given net (they
                # should all agree since a net→ESP32 is usually 1 pin).
                out.setdefault(name, gpio)
    return esp_ref, out


def check_board(name: str, netlist: str, json_name: str, dual_radio: bool) -> int:
    print(f"\n── {name} ──")
    if not os.path.exists(netlist):
        print(f"  ERROR: netlist missing: {netlist}"); return 1
    json_path = os.path.join(ELRS, json_name)
    if not os.path.exists(json_path):
        print(f"  ERROR: json missing: {json_path}"); return 1

    esp_ref, pins = gather_esp32_nets(netlist)
    if not pins:
        print(f"  ERROR: no ESP32 pins resolved"); return 1

    with open(json_path) as f:
        conf = json.load(f)

    rules = list(NET_TO_FIELD_COMMON)
    if dual_radio:
        rules += NET_TO_FIELD_RADIO_B

    errors = 0
    seen_fields: set[str] = set()
    for net_name, gpio in sorted(pins.items()):
        matched = False
        for rx, field in rules:
            if not rx.match(net_name):
                continue
            if field not in conf:
                continue
            want = conf[field]
            seen_fields.add(field)
            if gpio == want:
                print(f"  OK    {field:16s} net={net_name:9s} GPIO{gpio}")
            else:
                print(f"  FAIL  {field:16s} net={net_name:9s} schematic=GPIO{gpio}  json={want}")
                errors += 1
            matched = True
            break
        if not matched:
            # Not tied to a JSON field — still print for visibility
            pass

    # Any configured JSON pins for which we saw no matching net?
    expected_fields = {f for _, f in rules if f in conf}
    missing = expected_fields - seen_fields
    for m in sorted(missing):
        # led_rgb and led are aliases — tolerate one missing if the other was seen
        if m == "led_rgb" and "led" in seen_fields:
            continue
        if m == "led" and "led_rgb" in seen_fields:
            continue
        print(f"  MISS  {m:16s} expected GPIO{conf[m]} — no net mapped")
        errors += 1

    print(f"  ESP32 ref: {esp_ref}, nets resolved: {len(pins)}, errors: {errors}")
    return errors


def main() -> int:
    rc = 0
    rc += check_board(
        "OpenRX-Lite",
        os.path.join(BASE, "OpenRX-Lite", "netlist.xml"),
        "OpenRX Lite 2400.json",
        dual_radio=False,
    )
    rc += check_board(
        "OpenRX-Lite-UFL",
        os.path.join(BASE, "OpenRX-Lite-UFL", "netlist.xml"),
        "OpenRX Lite 2400.json",
        dual_radio=False,
    )
    rc += check_board(
        "OpenRX-Mono",
        os.path.join(BASE, "OpenRX-Mono", "netlist.xml"),
        "OpenRX Mono LR1121.json",
        dual_radio=False,
    )
    rc += check_board(
        "OpenRX-Gemini",
        os.path.join(BASE, "OpenRX-Gemini", "netlist.xml"),
        "OpenRX Gemini LR1121.json",
        dual_radio=True,
    )
    print(f"\nTotal errors: {rc}")
    return 0 if rc == 0 else 1


if __name__ == "__main__":
    sys.exit(main())

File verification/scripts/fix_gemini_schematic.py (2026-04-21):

#!/usr/bin/env python3
"""
One-shot fixes for OpenRX-Gemini schematic (ELRS review prep):

1. Filter symbols:
     lib_id     DEA102700LT-6307A2 → 2450FM07D0034T
     footprint  FILTER-SMD_4P-L1.0-W0.5-L_DEA102700LT-XXX → FILTER-SMD_4P-L1.0-W0.5-L
2. Rename filter references:
     USB2 (Radio A, x≈390) → FL1
     USB1 (Radio B, x≈136) → FL2
3. Add/update LCSC Part + MPN + Manufacturer + Description on the filters.

Uses kicad-skip. Run from anywhere.
"""
from __future__ import annotations

import os
import sys

import skip

BASE = os.path.dirname(os.path.dirname(os.path.dirname(os.path.abspath(__file__))))
GEMINI_SCH = os.path.join(BASE, "OpenRX-Gemini", "esp32c3_lr1121_gemini.kicad_sch")

OLD_LIB_ID = "OpenRX-Shared:DEA102700LT-6307A2"
NEW_LIB_ID = "OpenRX-Shared:2450FM07D0034T"
OLD_FP = "OpenRX-Shared:FILTER-SMD_4P-L1.0-W0.5-L_DEA102700LT-XXX"
NEW_FP = "OpenRX-Shared:FILTER-SMD_4P-L1.0-W0.5-L"

# Rename: old ref → (new ref, approx x to confirm location)
RENAME = {
    "USB2": ("FL1", 390.0),   # Radio A, right side
    "USB1": ("FL2", 136.0),   # Radio B, left side
}


def norm(name: str) -> str:
    return name.replace(" ", "_")


def find_prop(sym, name: str):
    target = norm(name)
    for p in sym.property:
        if norm(p.name) == target:
            return p
    return None


def set_or_clone(sym, name: str, value: str):
    prop = find_prop(sym, name)
    if prop is not None:
        if prop.value != value:
            prop.value = value
            return True
        return False
    source = find_prop(sym, "Description") or find_prop(sym, "Datasheet")
    if source is None:
        return False
    new_prop = source.clone()
    new_prop.name = name
    new_prop.value = value
    return True


def main() -> int:
    if not os.path.exists(GEMINI_SCH):
        print(f"ERROR: not found: {GEMINI_SCH}", file=sys.stderr)
        return 1

    sch = skip.Schematic(GEMINI_SCH)
    touched = 0
    renamed = 0

    for sym in list(sch.symbol):
        ref = sym.property.Reference.value
        lib_id = sym.lib_id.value

        if lib_id != OLD_LIB_ID and ref not in RENAME:
            continue

        # Swap lib_id on old DEA instances
        if lib_id == OLD_LIB_ID:
            sym.lib_id.value = NEW_LIB_ID
            print(f"  {ref}: lib_id → {NEW_LIB_ID}")
            touched += 1

            # Fix footprint
            fp_prop = find_prop(sym, "Footprint")
            if fp_prop is not None and fp_prop.value == OLD_FP:
                fp_prop.value = NEW_FP
                print(f"  {ref}: footprint → {NEW_FP}")

            # Ensure metadata reflects Johanson 2450FM07D0034T
            changed = False
            changed |= set_or_clone(sym, "Value", "2450FM07D0034T")
            changed |= set_or_clone(sym, "Manufacturer", "JOHANSON")
            changed |= set_or_clone(sym, "MPN", "2450FM07D0034T")
            changed |= set_or_clone(sym, "LCSC Part", "C2651081")
            changed |= set_or_clone(sym, "LCSC Part_1", "C2651081")
            changed |= set_or_clone(
                sym,
                "Datasheet",
                "https://www.lcsc.com/datasheet/C2651081.pdf",
            )

        # Rename refs
        if ref in RENAME:
            new_ref, expected_x = RENAME[ref]
            ref_prop = sym.property.Reference
            ref_prop.value = new_ref
            print(f"  {ref} → {new_ref} (at x≈{expected_x})")
            renamed += 1

    sch.write(GEMINI_SCH)
    print(f"\nSaved. Filter symbols migrated: {touched}, refs renamed: {renamed}")
    return 0


if __name__ == "__main__":
    sys.exit(main())

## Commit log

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2026-03-23 Add OpenRX-Lite: budget 2.4GHz receiver (ESP32-C3 + SX1281)
    Smallest/cheapest receiver. No PA/LNA, ceramic antenna, 16x12mm.
    Includes SCHEMATIC.md, BOM.md, imported LCSC libs, datasheets.
    KiCad schematic/PCB are starter shells awaiting capture.
    [OpenRX-Lite.kicad_pcb, OpenRX-Lite.kicad_sch]
2026-03-23 Add OpenRX-Nano: standard 2.4GHz with RFX2401C PA+LNA
    Mid-range all-rounder. ESP32-C3 + SX1281 + RFX2401C, UFL, 20x13mm.
    First receiver aligned to RFX2401C front-end standard.
    [OpenRX-Nano.kicad_pcb, OpenRX-Nano.kicad_sch]
2026-03-23 Add OpenRX-900: budget sub-GHz receiver (ESP32-C3 + LR1121)
    Budget long-range receiver using LR1121 in sub-GHz only mode.
    LR1121 pinout needs reconciliation before schematic capture.
    [OpenRX-900.kicad_pcb, OpenRX-900.kicad_sch]
2026-03-23 Add OpenRX-Dual: dual-band switchable receiver (ESP32-C3 + LR1121)
    Single LR1121 with both sub-GHz and 2.4GHz RF paths.
    Still uses SE2431L in docs, pending RFX2401C migration.
    [OpenRX-Dual.kicad_pcb, OpenRX-Dual.kicad_sch]
2026-03-23 Add OpenRX-PWM: 6ch PWM receiver for fixed wing (ESP32-C3 + SX1281)
    PWM outputs for servos/ESCs. GPIO allocation documented with
    4ch (safe) and 6ch (DIO2 switching) options.
    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
    [OpenRX-PWM.kicad_pcb, OpenRX-PWM.kicad_sch]
2026-03-23 Add OpenRX-Gemini: flagship Xrossband receiver (ESP32-C3 + 2x LR1121)
    Simultaneous 2.4GHz + 900MHz Gemini mode. Dual LR1121 on shared
    SPI bus. Tightest GPIO allocation of the family.
    Still uses SE2431L on 2.4GHz path, pending RFX2401C migration.
    [OpenRX-Gemini.kicad_pcb, OpenRX-Gemini.kicad_sch]
2026-03-23 Consolidate docs: 1 README + KICAD_WORKFLOW + 1 DESIGN.md per receiver
    - Merge SCHEMATIC.md + BOM.md into single DESIGN.md per receiver
    - Delete OPENRX_ELRS_4_RECEIVER_PORTFOLIO.md (content integrated)
    - Delete REPO_AUDIT_2026-03-23.md (issues addressed)
    - Fold CORE_BOM into README.md architecture table
    - Rename KICAD_WORKFLOW_AND_ELRS_COMPATIBILITY.md to KICAD_WORKFLOW.md
    - Rewrite KICAD_WORKFLOW with step-by-step capture instructions
    - Add shared libs and starter shared sheet from audit agent
    [OpenRX-Lite.kicad_sch, esp32c3_sx1281_rx_core.kicad_sch]
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2026-03-23 Fix RF path: DEA102700LT-6307A2 only, no discrete matching
    RadioMaster uses only the DEA LPF between SX1281 and antenna/FEM
    on all their receivers. Remove stale L-match and pi-filter references.
    Add mandatory 0.3pF 5th harmonic cap on RFX2401C ANT output.
2026-03-23 Fix all DESIGN.md: RFX2401C, DEA LPF, LR1121 pinout, FEM control
    - Lite: remove L-match network, use DEA102700LT-6307A2 only
    - Nano: clarify DEA LPF path, mark 0.3pF as mandatory, SE2431L as EOL
    - 900: fix LR1121 RFSW description, confirm 4x4mm package
    - Dual: SE2431L→RFX2401C, FEM via LR1121 RFSW not MCU GPIO, BOM $9→$7.62
    - PWM: SE2431L→RFX2401C, DEA LPF + 0.3pF path, BOM $7.40→$6.02
    - Gemini: SE2431L→RFX2401C, fix FEM control model, BOM $10.84→$9.46
    [OpenRX-Lite.kicad_sch]
2026-03-23 Update all DESIGN.md: TLV75533 X2SON LDO, XL-1010 1x1mm LED
    - Lite/Nano/900/Dual: ME6211 SOT-23-5 → TLV75533PDQNR X2SON-4 (1x1mm)
    - Gemini: keeps AP2112K (600mA needed for dual radios)
    - PWM: keeps AMS1117 (needs >6V input range)
    - All: WS2812B-2020 → XL-1010RGBC-WS2812B (1x1mm)
    - Updated cap values for TLV755 (1uF local + 10uF bulk)
    [OpenRX-Lite.kicad_sch, esp32c3_sx1281_rx_core.kicad_sch]
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2026-03-23 Unify library tables, import RFX2401C, Lite schematic capture
    - All 6 projects now share OpenRX-Shared + OpenRX-Lite lib tables
    - Import RFX2401C (C19213) into shared library with 3D model path fix
    - OpenRX-Lite schematic: 0 ERC errors (captured in KiCad GUI)
    - Add .gitignore for .lck and .history files
    [OpenRX-Lite.kicad_pcb, OpenRX-Lite.kicad_sch, esp32c3_sx1281_rx_core.kicad_sch]
2026-03-23 Fix passive footprints to 0402/0603, add LCSC part numbers
    - All caps/resistors: 0201 → 0402 (1005 Metric)
    - 10uF bulk caps: 0402 → 0603 (1608 Metric)
    - Added LCSC field to all 23 passives:
    100nF=C1525, 1uF=C52923, 10uF=C15525, 10pF=C32949,
    470nF=C1543, 1nF=C1523, 10k=C25744
    - All JLCPCB basic parts, zero extended part setup fees on passives
    [OpenRX-Nano.kicad_sch, esp32c3_sx1281_rx_core.kicad_sch]
2026-03-23 Switch passives to 0201 with correct LCSC basic parts
    - 100nF: C14858 (0201 X5R 6.3V)
    - 1uF: C77857 (0201 X5R 6.3V)
    - 10pF: C14854 (0201 C0G 25V)
    - 470nF: C304534 (0201 X5R 6.3V)
    - 1nF: C80390 (0201 X7R 25V)
    - 10k: C172043 (0201 1%)
    - 10uF: C15525 (0603 X5R 10V, no 0201 available)
    [esp32c3_sx1281_rx_core.kicad_sch]
2026-03-23 10uF caps to 0402 (C15525), all other passives stay 0201
    [esp32c3_sx1281_rx_core.kicad_sch]
2026-03-23 Add LCSC fields to all 24 passives in shared schematic
    [esp32c3_sx1281_rx_core.kicad_sch]
2026-03-23 Separate Lite and Nano schematics, stop sharing one file
    Sharing one .kicad_sch between projects doesn't work - KiCad
    overwrites instance data when either project saves.
    - Lite: restored pre-Nano schematic as local esp32c3_sx1281_lite.kicad_sch
    - Nano: copied current shared sheet as local esp32c3_sx1281_rx_core.kicad_sch
    - Each project now has its own schematic file
    [OpenRX-Lite.kicad_sch, OpenRX-Nano.kicad_sch, esp32c3_sx1281_lite.kicad_sch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]
2026-03-23 Lite + Nano schematics: LCSC fields, fix 10uF to 0402, drop 0.3pF cap
    - All passives in both schematics have LCSC fields
    - 10uF caps fixed from 0201 to 0402 (C15525)
    - Nano C22 (0.3pF): removed discrete cap, use trace capacitance instead
    - 0 ERC errors on both schematics
    [esp32c3_sx1281_lite.kicad_sch, esp32c3_sx1281_rx_core.kicad_sch]
2026-03-23 OpenRX-900: add all LCSC fields, fix 4.7uF to 0402
    - C20 (4.7uF): C23733, footprint fixed from 0201 to 0402
    - R5/R6/R7 (100k): C25741, RFSW pull-downs
    - L1 (10uH): C1035, 0603 DC-DC inductor
    - U4 (LR1121): C7498014
    - U5 (32MHz TCXO): C22434888
    - T1 (Johanson IPD): C19842466
    - JP1 (UFL): C88374
    - 0 ERC errors, all components have LCSC fields
    [OpenRX-900.kicad_sch, esp32c3_lr1121_900.kicad_sch]
2026-03-23 OpenRX-Dual: set up project, copy 900 schematic as base
    Copy esp32c3_lr1121_900.kicad_sch as starting point.
    Next step: add RFX2401C + DEA LPF + second UFL for 2.4GHz path in KiCad GUI.
    Wire LR1121 RFIO_HF → DEA → RFX2401C, RFSW DIO5/DIO6 → RXEN/TXEN.
    [OpenRX-Dual.kicad_sch, esp32c3_lr1121_dual.kicad_sch]
2026-03-23 OpenRX-Dual: complete schematic, 0 ERC errors, all LCSC fields
    Dual-band switchable receiver based on 900 schematic plus:
    - RFX2401C (C19213) on 2.4GHz path via DEA LPF
    - LR1121 RFSW DIO5/DIO6 drive RFX2401C RXEN/TXEN
    - Second UFL for 2.4GHz antenna
    - 1uF + 220pF VDD decoupling for RFX2401C
    [esp32c3_lr1121_dual.kicad_sch]
2026-03-23 OpenRX-Gemini: set up project, copy Dual schematic as base
    [OpenRX-Gemini.kicad_sch, esp32c3_lr1121_gemini.kicad_sch]
2026-03-23 Add LCSC to 220R resistor (C25092) in Dual TCXO path
    220R series + 10pF DC-cut between TCXO output and LR1121 XTA
    per Semtech user manual recommendation.
    900 still needs this added in KiCad GUI.
    [esp32c3_lr1121_dual.kicad_sch, esp32c3_sx1281_rx_core.kicad_sch]
2026-03-23 Fix 220R LCSC to C25092, add TCXO series resistor to 900
    - 220R 0201 1%: C25092 (was incorrectly C25741/100k)
    - Both 900 and Dual now have correct 220R + 10pF on TCXO→XTA path
    - Nano: RFX2401C VDD now connected to +3V3
    - All 4 schematics: 0 ERC errors
    [esp32c3_lr1121_900.kicad_sch, esp32c3_lr1121_dual.kicad_sch]
2026-03-23 Fix crystal load caps: 10pF → 18pF (C71153) on all 4 receivers
    CJ17-400001010B20 crystal has CL=10pF. With 10pF load caps and
    ~2pF stray, effective load was only 7pF (30% low). Changed to 18pF
    giving ~11pF effective load, matching the crystal spec.
    C71153 = Samsung CL03C180JA3NNNC, 18pF C0G 25V 0201.
    [esp32c3_lr1121_900.kicad_sch, esp32c3_lr1121_dual.kicad_sch, esp32c3_sx1281_lite.kicad_sch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]
2026-03-23 Fix Gemini crystal load caps to 18pF (C62164), matching Lite and Mono
    [OpenRX-900.kicad_pcb, OpenRX-900.kicad_sch, OpenRX-Duak.kicad_pcb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]
2026-03-23 Add LCSC C430052 for 24nH XTAL_P inductor on Mono
    Mono L2 (24nH 0201) was missing LCSC field.
    Lite still needs 24nH inductor added in KiCad GUI.
    Gemini is parked — still a Mono copy, not yet dual-radio.
    [esp32c3_lr1121_mono.kicad_sch]
2026-03-23 OpenRX-Gemini: dual LR1121 schematic complete, 0 ERC errors
    - Radio 1 (U4): sub-GHz via Johanson IPD → JP1 UFL
    - Radio 2 (U9): 2.4GHz via RFX2401C (U10) → DEA (USB2) → JP3 UFL
    - Shared SPI bus (SCK/MISO/MOSI), separate NSS/IRQ/BUSY/RST per radio
    - Radio 2 control: GPIO10=NSS2, GPIO9=IRQ2, GPIO1=BUSY2, GPIO0=RST2
    - FEM driven by Radio 2 RFSW (DIO5→RXEN, DIO6→TXEN)
    - Radio 1 DIO5/DIO6 have 100k pull-downs (disconnected from FEM)
    - No LED (GPIO10 used for NSS2), no boot button (GPIO9 used for IRQ2)
    - Still needs: 10k pull-up on NSS2
    [OpenRX-Lite.csv, OpenRX-Mono.csv, esp32c3_lr1121_gemini.kicad_sch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]
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2026-03-23 Swap all solder pads to 1.2x2.0mm rounded (25%) across Lite, Mono, Gemini
    [OpenRX-Gemini.csv, esp32c3_lr1121_gemini.kicad_sch, esp32c3_lr1121_mono.kicad_sch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]
2026-03-23 Swap 32MHz TCXO to smaller 2016 package (C22381772)
    OW2EL89 (3225, 3.2x2.5mm) → OW7EL89 (2016, 2.0x1.6mm)
    Same YXC family, same pinout, same specs. Saves 1.2x0.9mm per TCXO.
    Affects Mono (1x) and Gemini (2x).
    [OpenRX-Gemini-lcsc.csv, OpenRX-Lite-lcsc.csv, OpenRX-Mono-lcsc.csv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]
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2026-03-23 Final topology: Mono + Gemini netlist with SKY13588 RF switch
    - SKY13588-460LF imported into shared library
    - Complete netlist for Mono (1×LR1121 + SKY13588 + Johanson IPD + DEA LPF → 1 UFL)
    - Gemini = 2× Mono RF chains + ESP32-C3 True Diversity GPIO mapping
    - GPIO maps match official ELRS Generic C3 LR1121 and True Diversity targets
    - Routing notes for RF paths included
    - Mono needs complete GPIO rewire to match ELRS target
    [OpenRX-Gemini.kicad_pcb]
2026-03-23 FINAL_NETLIST v3: SKY13588 as band combiner, RFX2401C kept for 100mW
    Based on RadioMaster XR4 teardown analysis:
    - SKY13588 serves as both sub-GHz path switch AND band combiner
    - Johanson IPD in direct-tie mode (RX/TX_LP/TX_HP joined) → SKY13588 J1
    - 2.4GHz: RFIO_HF → DEA LPF → RFX2401C → SKY13588 J2
    - SKY13588 RFC → DC block → UFL → dual-band antenna
    - RFX2401C kept for 100mW market parity
    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
    [esp32c3_lr1121_mono.kicad_sch]
2026-03-23 FINAL_NETLIST v3.1: fix 4 issues from review
    1. SKY13588 is band-select switch, not sub-GHz path switch (direct-tie handles that)
    2. Add mandatory 0.3pF shunt on RFX2401C ANT pin to BOM and pin table
    3. Direct-tie described as deliberate 2-3dB tradeoff, not equivalent to switched
    4. radio_rfsw_ctrl must be custom, not default ELRS — use RadioMaster [15,0,12,8,8,6,0,5]
2026-03-23 Mono schematic v4: complete RF chain verified
    Verified netlist:
    - LR1121 → IPD (direct-tie, pins 6+8+9 joined) → SKY13588 J1 ✓
    - LR1121 RFIO_HF → DEA LPF → RFX2401C TXRX ✓
    - RFX2401C ANT → 0.3pF shunt → SKY13588 J2 ✓
    - SKY13588 RFC → UFL ✓
    - DIO7→V1, DIO8→V2 (band select) ✓
    - DIO5→RXEN, DIO6→TXEN (RFX2401C control) ✓
    - GPIO map matches Generic C3 LR1121 target ✓
    - Added LCSC to 220pF, RFX2401C, button
    - 1 ERC error: GPIO10 needs NC marker
    - 0.3pF has no LCSC (layout pad for tuning)
    [esp32c3_lr1121_mono.kicad_sch]
2026-03-24 Gemini: copy Mono schematic as base for dual-radio build
    [OpenRX-Mono.kicad_pcb, esp32c3_lr1121_gemini.kicad_sch, esp32c3_lr1121_mono.kicad_sch]
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2026-03-24 Apply JLCPCB 6-layer advanced DRC rules to Mono and Gemini
    Rules applied:
    - Min clearance: 0.09mm (3.5mil)
    - Min track width: 0.09mm (3.5mil)
    - Min via diameter: 0.25mm
    - Min via drill: 0.15mm
    - Min annular ring: 0.05mm
    - Min hole-to-hole: 0.25mm
    - Default net class clearance: 0.09mm (was 0.2mm — this was the override)
    - Default track width: 0.1mm
    - Zone clearance: 0.09mm (was 0.5mm)
    [OpenRX-Gemini.kicad_pcb, esp32c3_lr1121_gemini.kicad_sch]
2026-03-24 Repo cleanup: final state for handoff
    - Clean README with architecture, BOM, CE notes, status
    - Remove dated analysis files (absorbed into FINAL_NETLIST + KICAD_WORKFLOW)
    - Remove stale OpenRX-Dual (archived), ERC reports, backups, prl files
    - Updated .gitignore for .kicad_dru, production backups
    - CERN-OHL-S v2 license confirmed
    - 3 active projects: Lite, Mono, Gemini
    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
    [OpenRX-Gemini.kicad_pcb, OpenRX-Lite.kicad_pcb, OpenRX-Mono.kicad_pcb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]
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2026-03-25 Standardize repo: .gitignore, README, license, remove production from tracking
    - Standardize .gitignore to match ecosystem template
    - Add license section to README
    - Replace LICENSE stub with full CERN-OHL-S-2.0 text
    - Remove production/ from git tracking (generated, re-exportable)
    - Remove tracked iCloud artifacts (.history 2 files)
    [OpenRX-Gemini.kicad_pcb, V0.1_bom.csv, V0.1_designators.csv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]
2026-04-06 Update schematics: Mono RF rewiring, SKY13414 port mapping, shared libs
    Mono: disconnect IPD TX_LP (unused by ELRS), route TX_HP→RF3, RX→RF1,
    RFX2401C ANT→RF4. Matches BetaFPV SuperX topology.
    [OpenRX-Lite.kicad_pcb, OpenRX-Mono.kicad_pcb, esp32c3_lr1121_gemini.kicad_sch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]
2026-04-06 Add Lite-UFL variant, ELRS targets, new footprints and 3D models
    - OpenRX-Lite-UFL: UFL antenna variant of Lite ceramic
    - ELRS target JSONs: Lite 2400, Mono LR1121, Gemini LR1121
    - radio_rfsw_ctrl: [15,0,0,8,8,14,0,13] for Mono/Gemini
    - SKY13414 QFN-14 footprint + 3D model
    - 2450FM07D0034 filter footprint
    - BOM LCSC passives script
    [OpenRX-Lite-UFL.kicad_pcb, OpenRX-Lite-UFL.kicad_sch, esp32c3_sx1281_lite.kicad_sch]
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2026-04-06 Update all DESIGN.md docs: RF paths, GPIO maps, rfsw_ctrl, known bugs
    - Mono: new SKY13414 port mapping (RF1=RX, RF3=TX_HP, RF4=2.4GHz),
    rfsw_ctrl [15,0,0,8,8,14,0,13], GPIO map, impedance notes
    - Lite/Lite-UFL: GPIO map, no-boot-button note, SPI pin difference
    - Gemini: document DIO7-2/DIO8-2 wiring bug, stale component list
    - README: current lineup table
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2026-04-28 Set via netclass + dimension defaults to 0.3/0.2mm on all 4 boards
    [OpenRX-Gemini.kicad_pcb, OpenRX-Lite-UFL.kicad_pcb, OpenRX-Lite.kicad_pcb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]
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
